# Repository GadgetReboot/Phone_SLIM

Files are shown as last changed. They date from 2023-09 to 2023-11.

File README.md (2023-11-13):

# Phone_SLIM
POTS Telephone Subscriber Line Interface Module
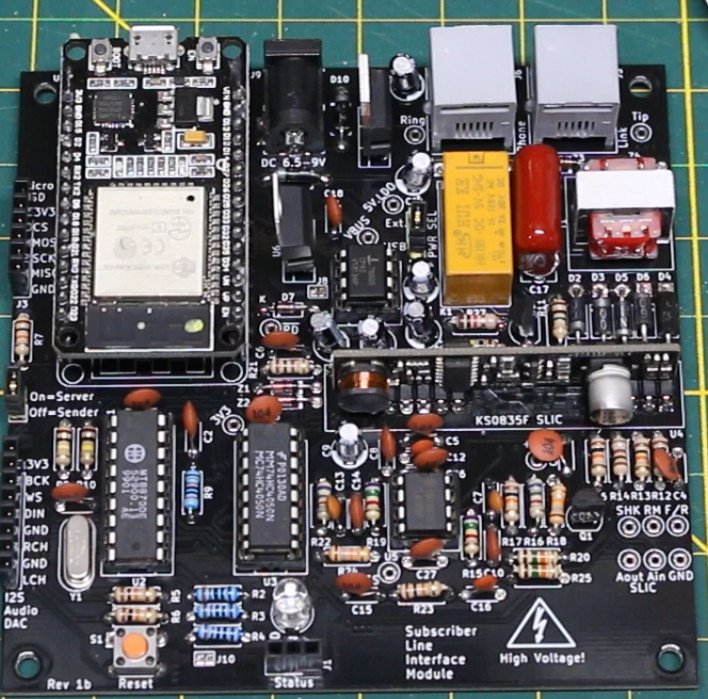
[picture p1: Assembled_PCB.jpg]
PCB
<br><br><BR><BR>
# Usage Notes
> [!NOTE]
> * This project is intended for hobby/personal use to explore how the plain old telephone service works.<br>
> * The PCB isn't designed to integrate with a live phone line. It is intended to create an offline system for local use.<br><br>

* It is recommended to add a TO-220 heat sink to the 3.3v regulator in case it gets too hot. I used [Wakefield-Vette 274-3AB](https://www.digikey.com/en/products/detail/wakefield-vette/274-3AB/2351871)  along with thermal paste and a nut/screw I had around.  <br>
* One pcb is needed for each phone/modem/etc.  One board has to have a jumper installed on J5 to act as a Server node and the other board(s) must have the jumper vacant to act as Sender nodes.<br>
* The Server board must connect to a WiFi router to function properly.  The SSID and Password for the router must be defined by editing the "arduino_secrets.h" file before compiling the sketch.<br>
* The telephone numbers are 7 digits long and are configured by editing the "project_globals.cpp" file and changing the numbers assigned to remotePhoneNumber and localPhoneNumber.<br>
* The region can be configured by uncommenting the desired line in the "project_globals.cpp" file, setting myRegion equal to North America or UK.<br><BR>

* Each board should be powered from an external 5 volt DC supply capable of 500mA since each board can draw several hundred mA.<BR>
* USB power can be used for programming and some testing, but the board may not be as stable as when powered externally.<BR>
* Set the power jumper J8 for USB or EXT as needed.<BR><BR>

# Parts
* The transformer is a 600:600 ohm audio isolation type.  The part used in the prototypes is from Ali Express, such as the red 4 pin ones here with description words such as EL14 included: https://s.click.aliexpress.com/e/_Dmlkp3z <BR><BR>

# Powering Up Two Nodes
* Power up the Server board first and wait for the blue LED to light up on the ESP module's built in LED to indicate it has joined the WiFi router.<br>
* Then power up the Sender board so it can try to auto-pair with the Server board over ESP-NOW.  In the future, software may be improved so the Sender board will auto-pair whenever the Server board is ready.<BR><BR>

* Check out this similar project being worked on: https://github.com/ktownsend-personal/RetroPhone
<br><br>
Shield: [][cc-by-sa]

This work is licensed under a
[Creative Commons Attribution-ShareAlike 4.0 International License][cc-by-sa].

[][cc-by-sa]

[cc-by-sa]: http://creativecommons.org/licenses/by-sa/4.0/
[cc-by-sa-image]: https://licensebuttons.net/l/by-sa/4.0/88x31.png
[cc-by-sa-shield]: https://img.shields.io/badge/License-CC%20BY--SA%204.0-lightgrey.svg

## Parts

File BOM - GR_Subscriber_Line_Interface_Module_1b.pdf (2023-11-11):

Subscriber Line Interface Module BOM

Item # | Reference Designator | Qty | Manufacturer | Mfg Part # | Description / Value | Package/Footprint | Type | Instructions / Notes
1 | C12 C16 | 2 | KYOCERA AVX | SR215C102KARTR1 | CAP CER 1000PF 50V X7R RADIAL | 5mm Pitch | THRU-HOLE
2 | C7 C13 | 2 | TDK | FA28X7R1H682KNU06 | CAP CER 6800PF 50V X7R RADIAL | 5mm Pitch | THRU-HOLE
3 | C1 C2 C3 C4 C5 C6 C8 C10 C11 C14 C15 C18 C24 C25 C26 | 15 | Vishay | K104K15X7RF5TH5 | 0.1 µF ±10% 50V Ceramic Capacitor X7R Radial | 5mm Pitch | THRU-HOLE
4 | C9 C19 C20 C21 C22 C23 | 6 | Panasonic | ECA-1CM100I | 10 µF 16 V Aluminum Electrolytic Capacitor Radial | 2.5mm Pitch | THRU-HOLE
5 | C17 | 1 | Panasonic | ECW-F2105HA | Film Capacitor 1.0uF 250VDC 3% MPP L/S=15mm | Radial | THRU-HOLE
6 | D2 D3 D5 D6 D8 | 5 | Diotec Semiconductor | 1N4004 | Diode 400 V 1A Through Hole DO-41/DO-204AC | DO-41 | THRU-HOLE
7 | D7 | 1 | onsemi | 1N4148 | Diode 100 V 200mA Through Hole DO-35 | DO-35 | THRU-HOLE
8 | D9 | 1 | Diodes Inc | 1N5817-T | DIODE SCHOTTKY 20V 1A DO41 | DO-41 | THRU-HOLE
9 | D1 | 1 | Everlight Electronics Co Ltd | EALP05RDMRGBA0 | 5mm RGB LED Common Anode | 5mm, T-1 3/4 | THRU-HOLE
10 | D4 | 1 | Littelfuse Inc. | P6KE82CA | TVS DO15 70.1V 600W BIDIR | DO-15 | THRU-HOLE
11 | J5 | 1 | Sullins | PREC002SAAN-RC | Connector Header Through Hole 2 position 0.100" | 2POS | THRU-HOLE
12 | J1 | 0 | | | | | | Do Not Install
13 | J4 | 0 | | | | | | Do Not Install
14 | J2 | 0 | | | | | | Do Not Install
15 | J3 J9 | 0 | | | | | | Do Not Install
16 | J8 | 1 | Sullins | PREC003SAAN-RC | Connector Header Through Hole 3 position 0.100" | 3POS | THRU-HOLE
17 | J10 | 1 | CUI Devices | PJ-202A | Power Barrel Jack 2.10mm ID, 5.50mm OD Through Hole, Right Angle 3POS | | THRU-HOLE
18 | J6 J7 | 2 | Ckmtw(Shenzhen Cankemeng) | R-RJ11R06P-A800 | RJ11 RJ Receptacle Modular Connector | 6POS | THRU-HOLE
19 | J11 | 1 | Phoenix Contact | 5442206 | TERM BLK 2P SIDE ENT 5.08MM PCB | 2POS | THRU-HOLE
20 | K1 | 1 | Ningbo Keke New Era Appliance | HK19F-DC5V-SHG（Y) | Relay DPDT 5VDC Coil | 8PIN | THRU-HOLE
21 | Q2 | 1 | Onsemi | 2N3904TA | BJT NPN Transistor General Purpose | TO-92 135AR Leadformed | THRU-HOLE
22 | Q1 | 1 | Onsemi | 2N7000 | MOSFET TO92 N 60V 0.2A 5OHM 150C | TO-92 | THRU-HOLE
23 | R14 R21 | 2 | YAGEO | CFR-25JR-52-100R | RES 100 OHM 5% 1/4W AXIAL | Axial | THRU-HOLE
24 | R1 R3 R4 | 3 | YAGEO | CFR-25JR-52-300R | RES 300 OHM 5% 1/4W AXIAL | Axial | THRU-HOLE
25 | R27 | 1 | YAGEO | CFR-25JR-52-1K | RES 1K OHM 5% 1/4W AXIAL | Axial | THRU-HOLE
26 | R16 R22 | 2 | YAGEO | CFR-25JR-52-6K8 | RES 6.8K OHM 5% 1/4W AXIAL | Axial | THRU-HOLE
27 | R15 R19 R25 | 3 | YAGEO | CFR-25JR-52-7K5 | RES 7.5K OHM 5% 1/4W AXIAL | Axial | THRU-HOLE
28 | R2 R5 R6 R7 R12 R13 R17 R23 R26 | 9 | YAGEO | CFR-25JR-52-10K | RES 10K OHM 5% 1/4W AXIAL | Axial | THRU-HOLE
29 | R20 | 1 | YAGEO | CFR-25JR-52-15K | RES 15K OHM 5% 1/4W AXIAL | Axial | THRU-HOLE
30 | R18 R24 | 2 | YAGEO | CFR-25JR-52-18K | RES 18K OHM 5% 1/4W AXIAL | Axial | THRU-HOLE
31 | R8 R10 R28 | 3 | YAGEO | CFR-25JR-52-100K | RES 100K OHM 5% 1/4W AXIAL | Axial | THRU-HOLE
32 | R9 | 1 | YAGEO | CFR-25JR-52-300K | RES 300K OHM 5% 1/4W AXIAL | Axial | THRU-HOLE
33 | R11 | 1 | YAGEO | CFR-25JR-52-1M | RES 1Meg OHM 5% 1/4W AXIAL | Axial | THRU-HOLE
34 | S1 | 1 | TE Connectivity | 1825910-6 | 50mA Straight SPST 160gf 24V Plugin Tactile Switch | 4PIN | THRU-HOLE
35 | T1 | 1 | Sunrom | 5132 | Audio Isolation Transformer 600:600 Ohm 1:1 EI14 | 4 lead | THRU-HOLE | Info: https://www.sunrom.com/m/5132
36 | U3 | 1 | Texas Instruments | CD74HC4050E | IC BUFFER NON-INVERT 6V 16DIP | DIP16 | THRU-HOLE
37 | U1 | 2 | Sullins | PPTC151LFBN-RC | CONN HDR 15POS 0.1 TIN PCB | 15POS | THRU-HOLE | Two 15 pin female headers are installed so the user can plug in ESP32_DevKit_V1_DOIT module. For best alignment plug an ESP32 module into the headers and then solder to PCB.
38 | U7 | 1 | Renesas | ICL7660SIPAZ | IC REG CHARGE PUMP INV 45MA 8DIP | DIP8 | THRU-HOLE
39 | U4 | 1 | Shenzhen Ring&Tone | KS0835F | RING Subscriber Line Interface Circuit Module | SIP Special | THRU-HOLE | Purchased from AliExpress. Manufacturer: http://www.r-tone.com/contact-us
40 | U6 | 1 | ST Micro | LD1117AV33 | IC REG LINEAR 3.3V 1A TO220AB | TO-220 | THRU-HOLE

41 | U5 | 1 | Texas Instruments | LM358P | IC OPAMP GP 2 CIRCUIT 8DIP | DIP-8 | THRU-HOLE
42 | U2 | 1 | Microchip | MT8870DE1 | IC TELECOM INTERFACE 18DIP | DIP18 | THRU-HOLE
43 | Y1 | 1 | Abracon | ABL-3.579545MHZ-B2 | 3.579545 MHz ±20ppm Crystal 18pF 180 Ohms HC-49/US | HC-49/US | THRU-HOLE
44 | Z1 Z2 Z3 Z4 | 4 | Vishay | BZX55B2V4-TAP | DIODE ZENER 2.4V 500MW DO35 | DO-35 | THRU-HOLE

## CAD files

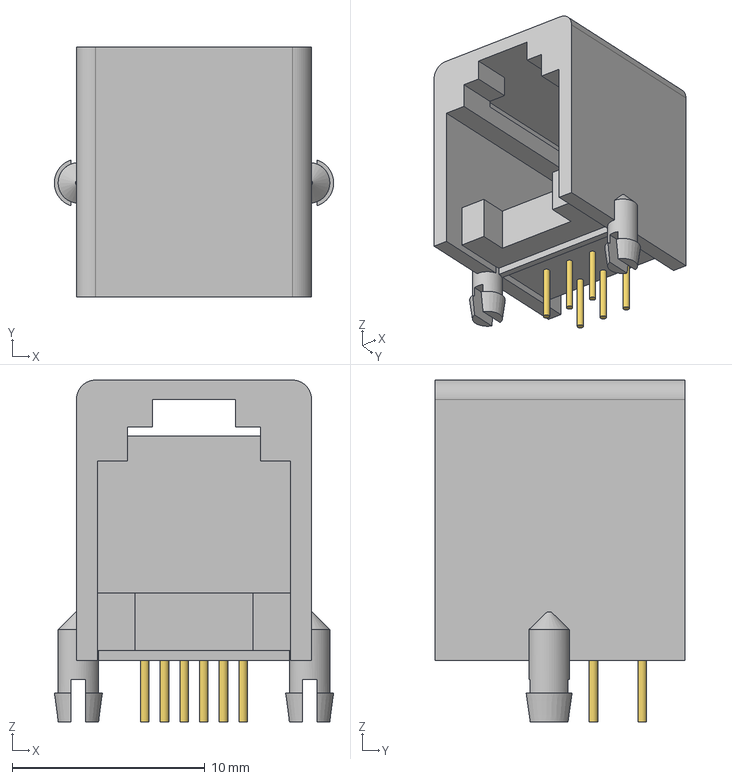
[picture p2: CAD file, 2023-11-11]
KiCad/3D_Models/TJ6P6C.stp
14.5 x 13.0 x 17.8 mm

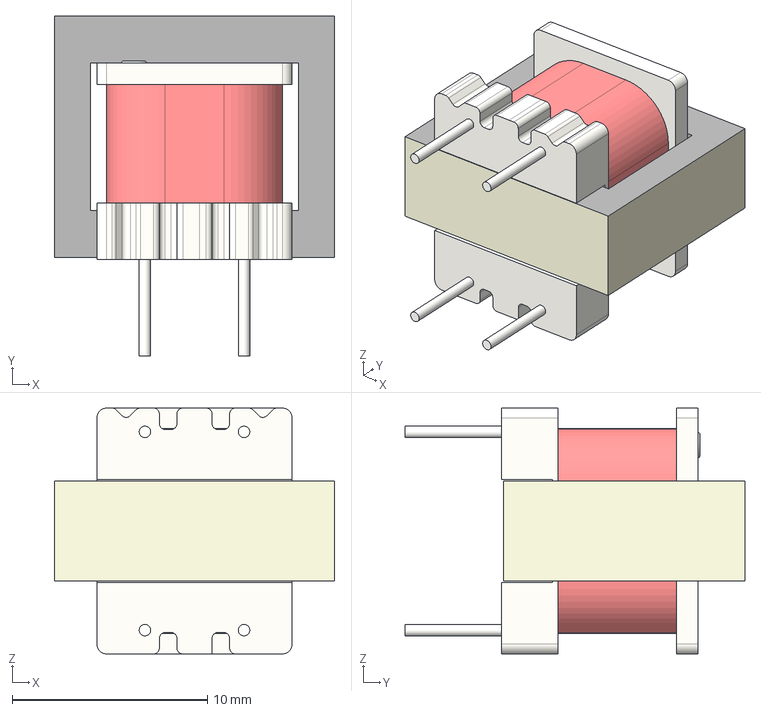
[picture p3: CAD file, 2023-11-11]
KiCad/3D_Models/EE14 Red Audio Transformer v3.step
14.3 x 17.4 x 12.6 mm

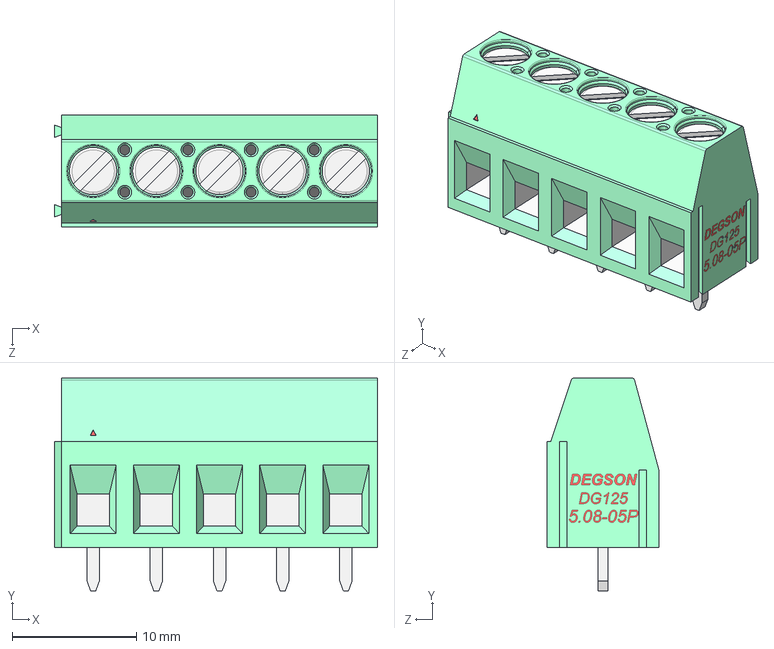
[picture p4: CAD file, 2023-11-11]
KiCad/3D_Models/DG125-5.08-05P-14-00AH.STEP
26.0 x 17.1 x 9.00 mm

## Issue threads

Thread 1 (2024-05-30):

Various errors loading Sketch

DAN-GITHUB-ACCESS, 2024-05-30:
Hello Gadget Reboot, I am contacting you here because I did not find any other information.

I ordered 5 Phone Line Simulator (POTS Land Line) boards from PCBWAY.

I would like to customize it so that I have a button. When I press the button the phone starts ringing. When the phone is answered, a greeting and then music is played from an SD card. If it is not answered, the ringing will stop after 5 times.

I haven't done that much with Arduino and not with such complex sketches.

But my problem is that when I want to load your sketch. Many errors are displayed that modules are missing.

Would it be possible to get a sketch where all modules are included and the required #INCLUDE is not <excluded>.

Thx Danny

GadgetReboot, 2024-05-30:
I don't know a lot about software so I was lucky to get everything working and I know things can break if new libraries are released or different board files for the chip being used.
What errors did you get?
I will try to flash the sketch in a newer Arduino IDE setup and see if it works easily or what I needed to do to get libraries installed.

GadgetReboot, 2024-05-31:
I just installed the latest Arduino IDE fresh on a clean system that has never had any of the files on it so there would be no residual things that get overlooked.
The first thing I'd try is verify which version of the ESP32 board file you are using because somewhere after the version 1 series, things started giving compile errors.
I used ESP32 board file version 1.0.6   and a bunch of weird errors went away.   If you use a newer board file you can temporarily downgrade to 1.0.6 and then upgrade again after, or set up a different IDE for using weird occasional configurations.   I don't know why the errors are there or if they're due to other libraries not working well together so I just lived with the dependency.

Here's the long list of exactly what I did from scratch:

SLIM_node Sketch Upload from scratch
Install Arduino IDE 2.3.2
Download sketch and unzip in folder called SLIM_node, and open the sketch in the IDE
Configure Arduino IDE for  ESP32 board file support following instructions on Espressif page, using Stable release link in Arduino preferences board manager URL  https://docs.espressif.com/projects/arduino-esp32/en/latest/installing.html
Then in Arduino IDE menu Tools/Board/Boards Manager,  search for ESP and install ESP by espressif  1.0.6   Newer board files cause compile errors
Choose the correct ESP32 board in Tools/Board/ESP32/DOIT ESP32 DEVKIT V1
Without having installed any other libraries yet, going step by step, clicking Verify to compile and check for errors, it can’t find RGBLed.h  so installed that by going to https://github.com/wilmouths/RGBLed   and clicking the green Code button, choose download zip and save it.
In the IDE choose menu item Sketch, Include Library, Add .Zip Library.  Navigate to the downloaded Zip file and click Open to install it.
Compiling again, it can’t find ESPAsyncWebServer
Install by going to https://github.com/me-no-dev/ESPAsyncWebServer and following the same procedure to download the zip and install the library.
Compiling again, it can’t find AsyncTCP
Install the same way from https://github.com/me-no-dev/AsyncTCP
Compiling again, it can’t find ArduinoJSON
Go to IDE menu Sketch/Include Library/Manage Libraries and search for ArduinoJSON by Benoit Blanchon.  Install version 6.19.4  since this was the version used for testing originally.
Compiling again, it can’t find MozziGuts.
Install Mozzi by going to https://github.com/sensorium/Mozzi and installing the library zip file with previous methods
Compile successful!

DAN-GITHUB-ACCESS, 2024-05-31:
Hello
Thank you for this fast answer.

Setup

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

Use Sketch from repository

Verify Sketch

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

RGBLed.h highlighted in the sketch.
RGBLed.h not included in the sketch folder

comment out

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

Verify Sketch

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

ESPAsyncWebServer.h highlighted in the sketch.
WiFi.h and ESPAsyncWebServer.h not included in the sketch folder

GadgetReboot, 2024-05-31:
Yeah those libraries need to be installed by downloading the zip files the way I described in my clean setup yesterday and then it should compile.

DAN-GITHUB-ACCESS, 2024-05-31:
Oh sorry, I didn't see the email at first. What is needed from the Mozzi .zip? everything ?

DAN-GITHUB-ACCESS, 2024-05-31:
Thank you very much, it worked.

Last question. When I use the board with an external power supply. Can I still use the USB port on the board for programming at the same time, or do I just have to use USB?

GadgetReboot, 2024-06-01:
Since the IDE is installing the whole zip library I just kept it all because it would probably break if I tried to delete files and it happens to need them.
External power and usb can be plugged in at the same time because diodes on the ESP module as well as the board prevent any back feeding if multiple sources are in use.

DAN-GITHUB-ACCESS, 2024-06-01:
Thank you again for your help and creating this board.

DAN-GITHUB-ACCESS, 2024-06-27:
Can you give me some help again?

How can I start and stop the ringing on the same board.
I only made it to the other board using a "sendTrunkMsg" message.

Thank you very much.

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

GadgetReboot, 2024-06-27:
It's been a while since I was doing testing with just making a phone ring on one board and I can't find any test code so if I were looking to add some kind of extra feature to the main code, I'd check if there's a spare input pin available on the ESP32 I can use to trigger a ring (can't remember if there's extra pins now).

Then I'd add some extra conditions to the runStateMachine()   part of the main INO sketch file to force a ring generating state as if someone were trying to call in from the other board.

There is a state called ringPhone   that gets assigned to  currState   when an incoming call normally rings the phone so I'd want to trigger that state in a test mode.

So in the case  Idle:      part of the runStateMachine() function, there's some if-statements there that wait for an event to go do something besides sit waiting for a command.
The last if-statement there  looks like:
      if (remoteRequestType == INCOMING_CALL) {
        clearRemoteNodeData();                           
        enteringNewState = true;
        currState = ringPhone;                           
      }

So I'd add a new if-statement right after that one that maybe does something like
if (reading in that spare GPIO test-ring pin is low) {
        enteringNewState = true;
        currState = ringPhone;                           
      }

Then there would be that extra way to make the local phone ring other than an income call message to ring it, by setting a spare pin low or whatever other method can be used to trigger it, and the state machine jumps to the phone ring part.

Then to make the phone stop ringing of course, just pick it up and hang it up, or else hack in more if-statements to look for something like another GPIO low level reading to make it stop.

It looks like the only unused gpio pins are 1 2 and 3 on the schematic, 1 and 3 are UART and pin 2 is the on board LED for the module, so just for an experiment maybe one of those three can be assigned as input with pull up at the end of the setup() function and read in during that new if-statement to check if it's low and do the test ring.  I'd probably try gpio 2 (LED) since it is less likely to be used as an LED after the first setup lines of code (it's used to show when wifi is joined, which happens earlier in setup).

DAN-GITHUB-ACCESS, 2024-06-28:
Thanks for the help.

My board automatically starts in server mode and I can use the pin for a button.

I have now found that when I set the trigger with the button, the circuit first needs a status change. idle -> off-hook -> idle. then the phone rings.
So I would have to reinitialize the runStateMachine after pressing the button. But somehow that doesn't work.

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

DAN-GITHUB-ACCESS, 2024-06-28:
I did it. I was able to work with "enteringNewState“.

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

GadgetReboot, 2024-06-28:
Good that it worked - I'd have to get all back into the mindset to even remember how it all works after half a year away from it, and I don't have anything set up to even test with right now.  I had to use the ESP modules in another project.  But I'll be getting back at it maybe in a few months with a new audio switching board I now have so it can route calls between multiple nodes.  It'll take a bunch of hacking and slashing of software before that gets working and I'll have to re-learn how the messages function so I can intercept them and use them for multi node routing.

DAN-GITHUB-ACCESS, 2024-06-28:
Sounds interesting. Keep us informed about these cool things.

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

VladIPlay, 2025-01-14:
Hi, i found your board and videos on youtube and got sucked up into this rabbit hole :)
I will order some PCBs to play with it but i would want to know if it is possible to record on the SD card the 'calls'.
My idea is to show my nephews how phones were in the past and make them some games using landline phones.
As a bonus, i will try to add a mmwave sensor to trigger the phone to ring or something like this to make it more fun.
I am new to tinkering with electronics but with the software part i think i will manage.

VladIPlay, 2025-01-14:
Hi, i found your board and videos on youtube and got sucked up into this rabbit hole :)
I will order some PCBs to play with it but i would want to know if it is possible to record on the SD card the 'calls'.
My idea is to show my nephews how phones were in the past and make them some games using landline phones.
As a bonus, i will try to add a mmwave sensor to trigger the phone to ring or something like this to make it more fun.
I am new with tinkering with electronics but with the software part i think i will manage.

GadgetReboot, 2025-01-14:
> Hi, i found your board and videos on youtube and got sucked up into this rabbit hole :) I will order some PCBs to play with it but i would want to know if it is possible to record on the SD card the 'calls'.

I haven't tried so you'd have to experiment by using a reference project for SD read/write and put the code in the phone sketch and make sure it doesn't clash with anything else in the sketch.
Another way to save data just in the ESP32 flash directly is saving data using Preferences.   I also haven't done that before and it would have to be tested to make sure nothing clashes but I'd start with an example like this
https://randomnerdtutorials.com/esp32-save-data-permanently-preferences/

GadgetReboot, 2025-01-14:
.

GadgetReboot, 2025-01-14:
.

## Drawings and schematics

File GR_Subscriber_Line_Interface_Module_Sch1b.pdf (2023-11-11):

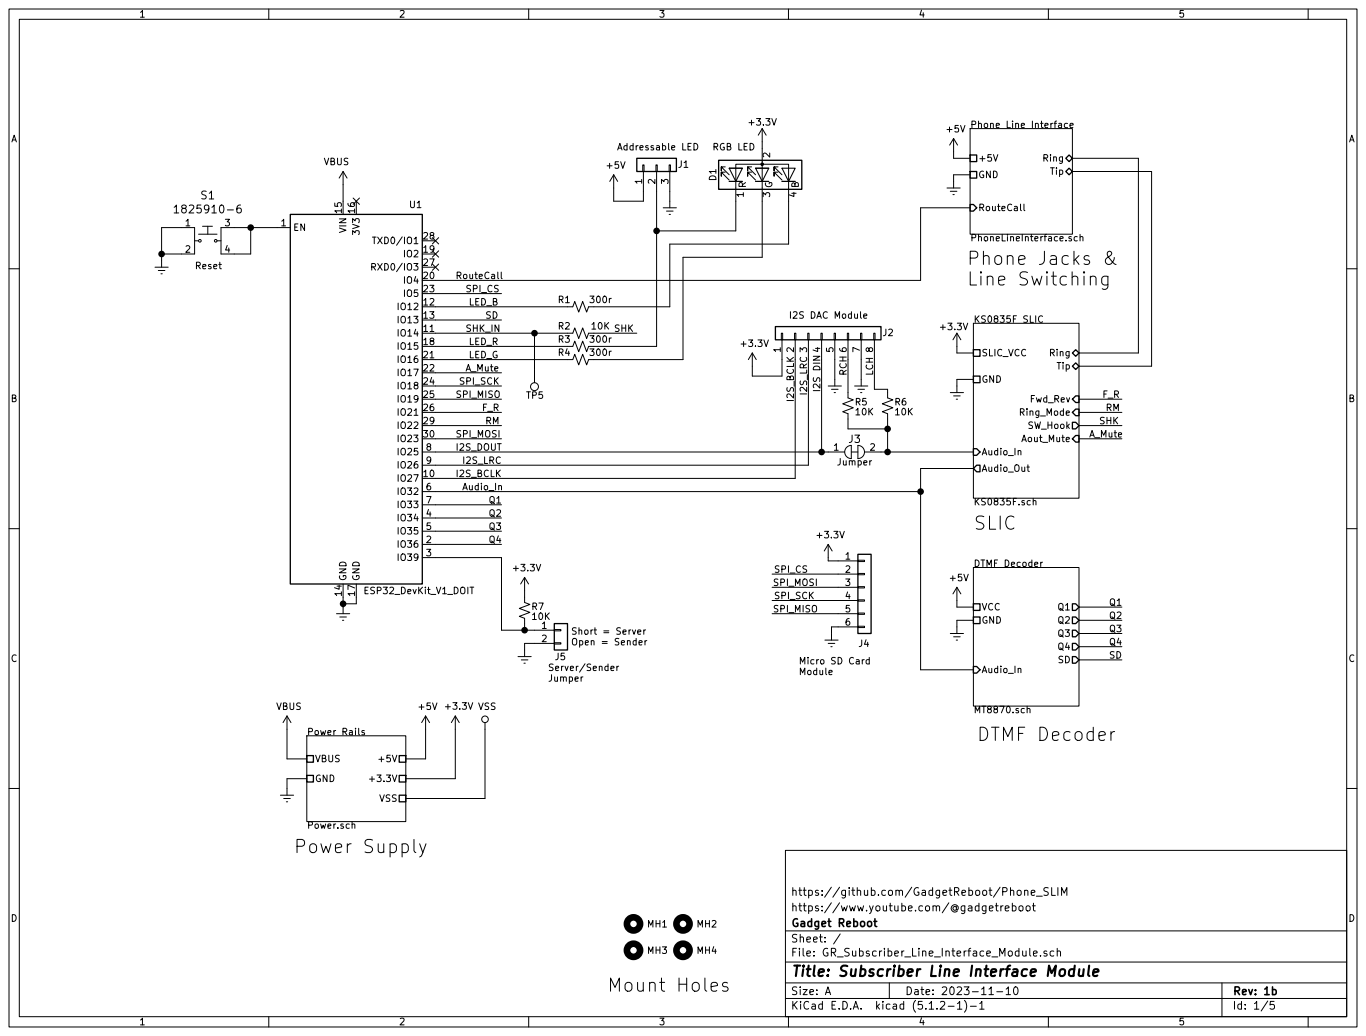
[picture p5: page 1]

I2S_LRC | I2S DIN | Jumper I2S_BCLK RCH LCH

A_Mute Power Rails Power.sch VBUS GND

I2S_LRC

https://github.com/GadgetReboot/Phone_SLIM
https://www.youtube.com/@gadgetreboot
File: GR_Subscriber_Line_Interface_Module.sch Sheet: / Gadget Reboot

Id: 1/5 Title: Subscriber Line Interface Module

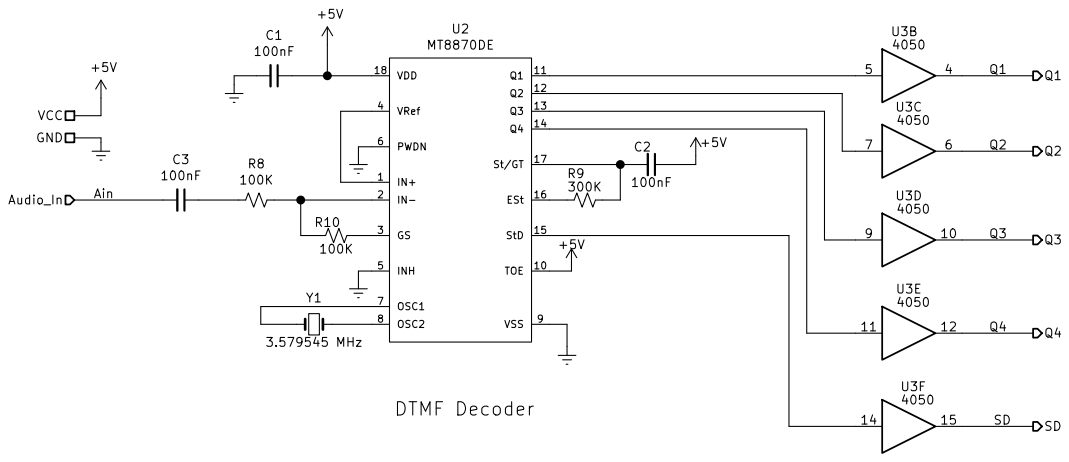
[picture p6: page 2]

https://github.com/GadgetReboot/Phone_SLIM
https://www.youtube.com/@gadgetreboot
File: MT8870.sch Sheet: /DTMF Decoder/ Gadget Reboot

Id: 2/5 Title: Subscriber Line Interface Module

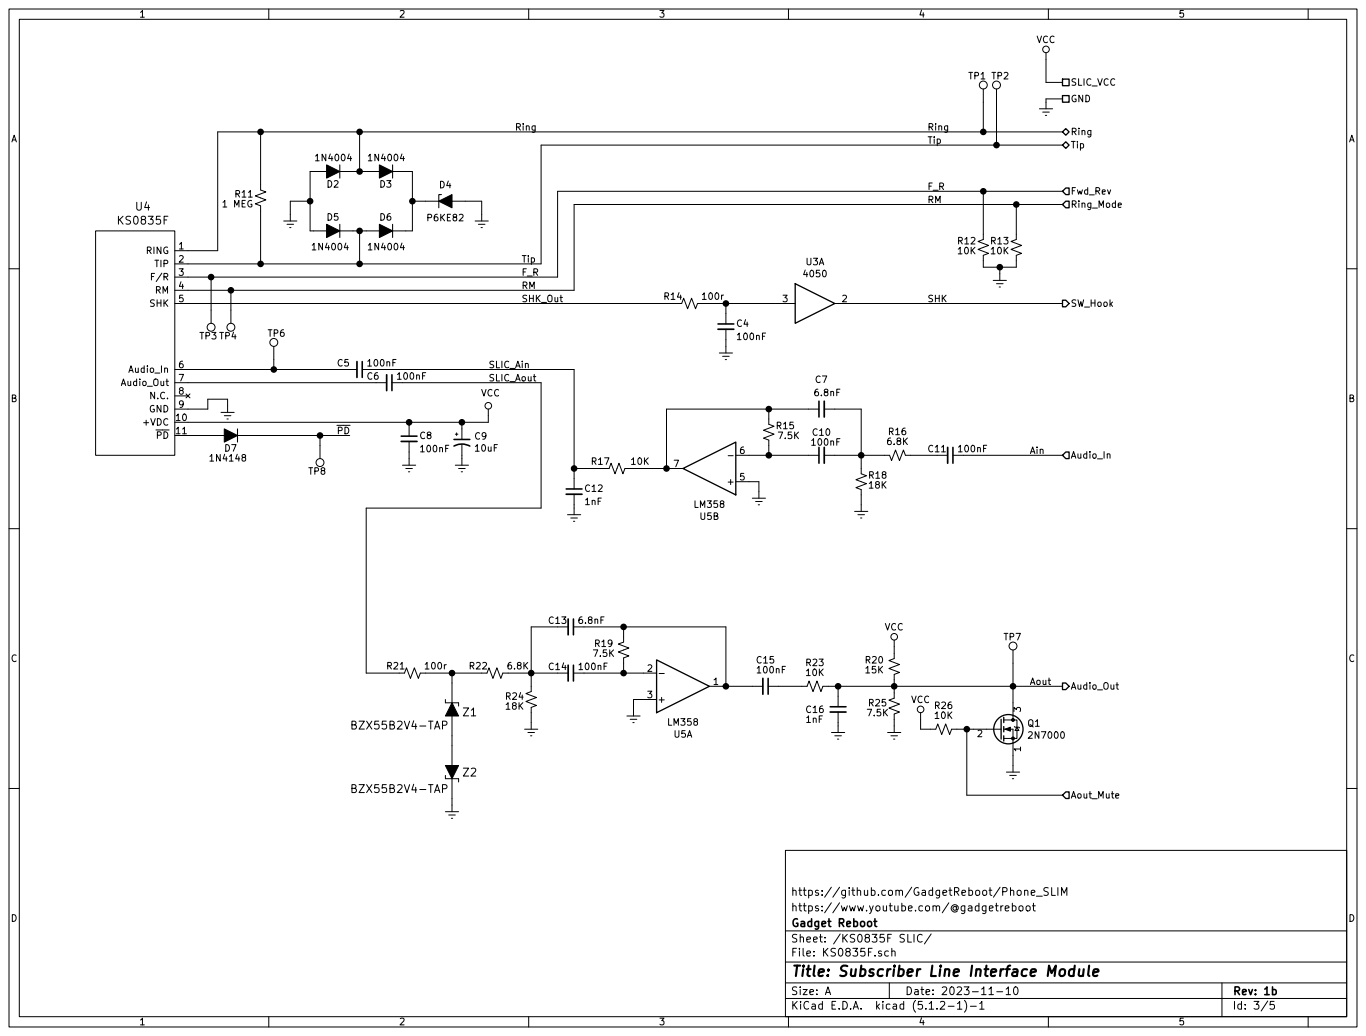
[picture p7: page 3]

https://github.com/GadgetReboot/Phone_SLIM
https://www.youtube.com/@gadgetreboot
File: KS0835F.sch Sheet: /KS0835F SLIC/ Gadget Reboot

Id: 3/5 Title: Subscriber Line Interface Module

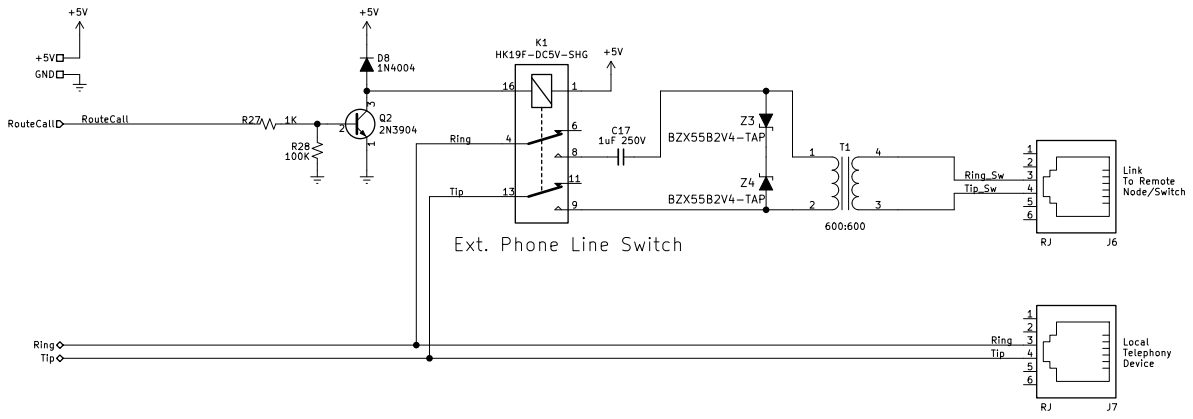
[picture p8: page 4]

Local Telephony Device Ring +5V GND

Link To Remote Node/Switch R28

https://github.com/GadgetReboot/Phone_SLIM
https://www.youtube.com/@gadgetreboot
File: PhoneLineInterface.sch Sheet: /Phone Line Interface/ Gadget Reboot

Id: 4/5 Title: Subscriber Line Interface Module

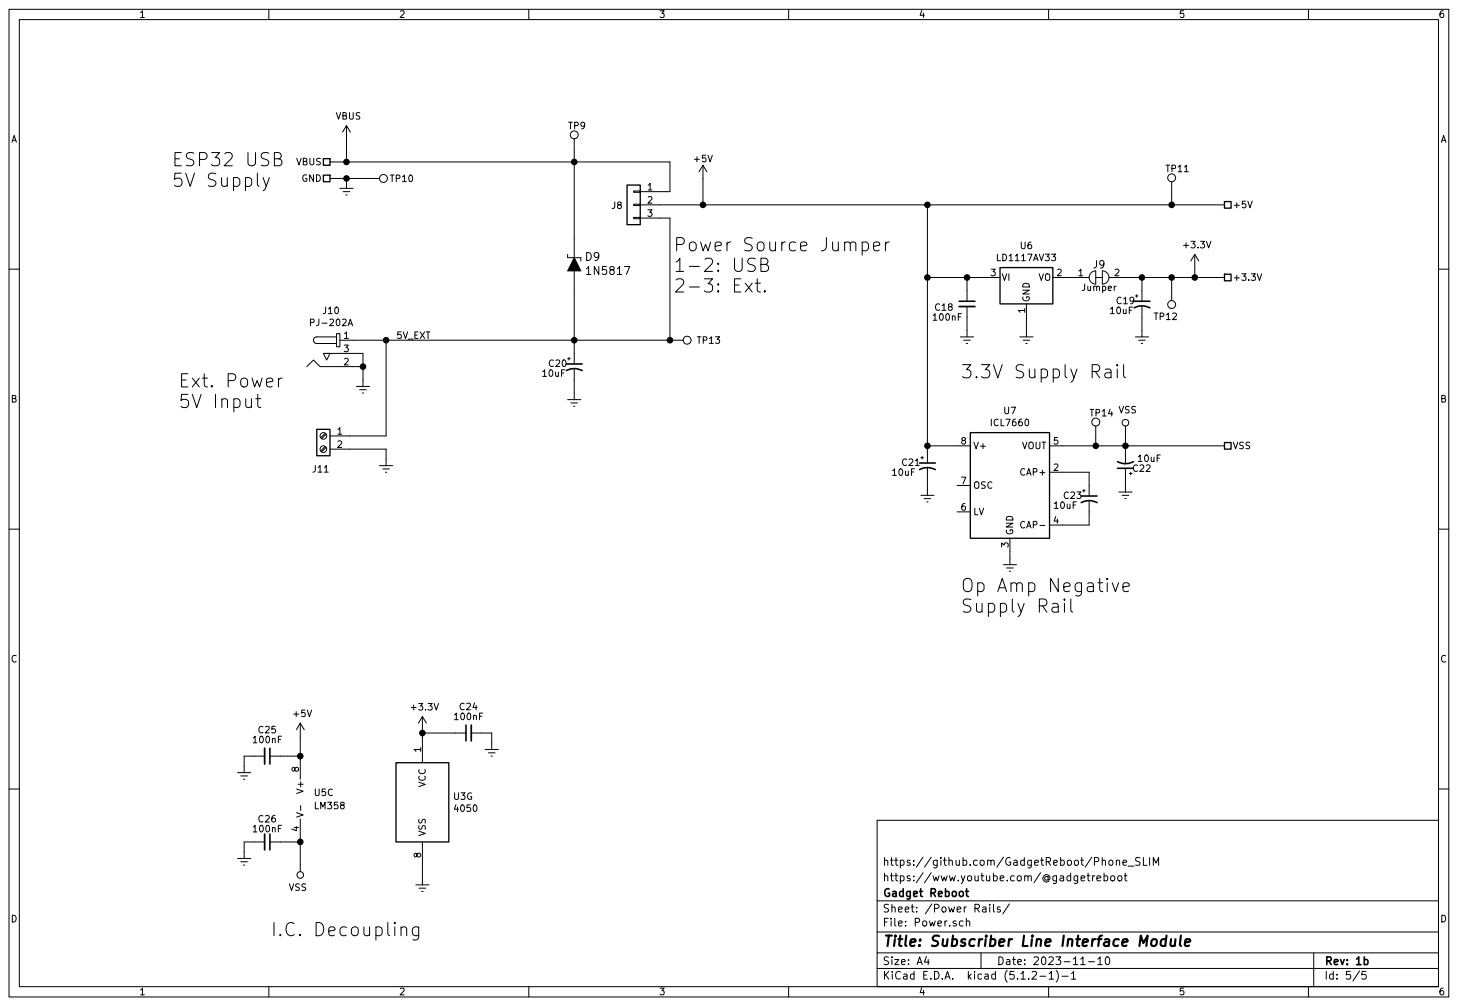
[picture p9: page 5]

https://github.com/GadgetReboot/Phone_SLIM V- 4 V+

https://www.youtube.com/@gadgetreboot
File: Power.sch Sheet: /Power Rails/ Gadget Reboot

Id: 5/5 Title: Subscriber Line Interface Module

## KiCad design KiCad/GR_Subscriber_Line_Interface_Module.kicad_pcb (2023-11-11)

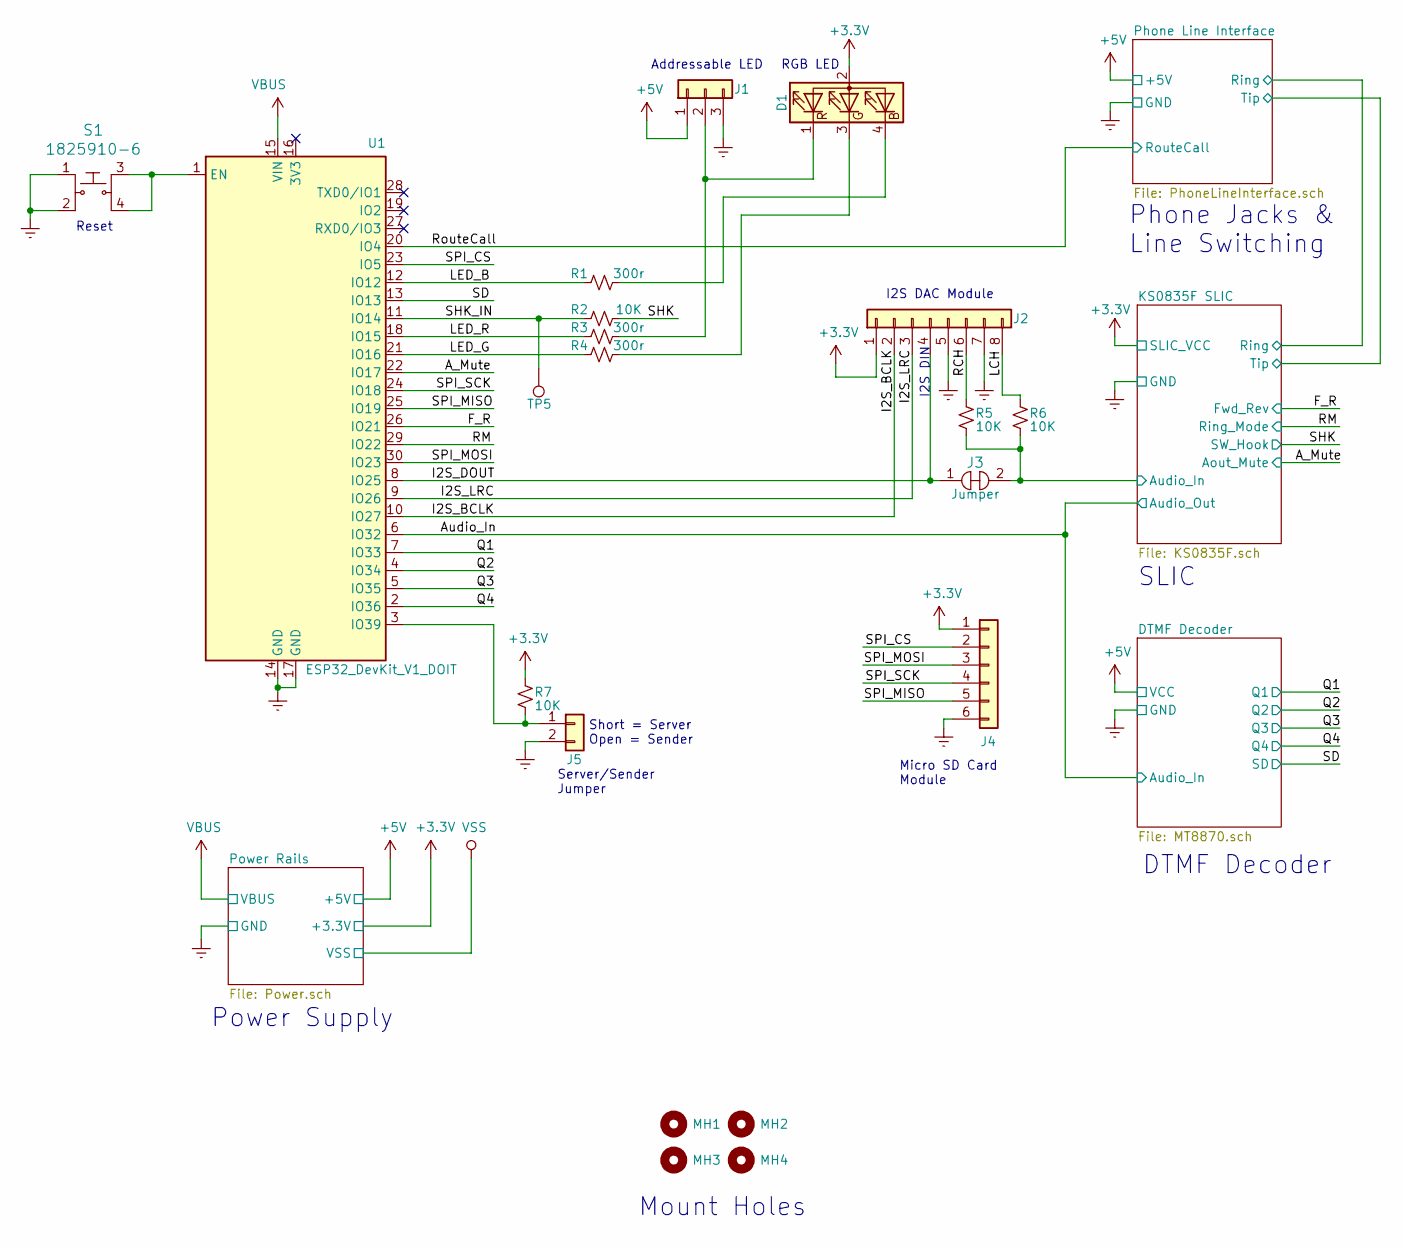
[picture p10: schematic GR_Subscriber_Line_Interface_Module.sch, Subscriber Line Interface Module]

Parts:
D1: LED_RAGB; LED_D5.0mm-4_RGB
J1: Conn_01x03; PinHeader_1x03_P2.54mm_Vertical
J2: Conn_01x08; PinHeader_1x08_P2.54mm_Vertical
J3: Jumper; SolderJumper-2_P1.3mm_Bridged_Pad1.0x1.5mm
J4: Conn_01x06; PinHeader_1x06_P2.54mm_Vertical
J5: Conn_01x02; PinHeader_1x02_P2.54mm_Vertical
MH1, MH2, MH3, MH4: MountingHole; MountingHole_3.2mm_M3
R1, R3, R4: 300r; R_Axial_DIN0207_L6.3mm_D2.5mm_P10.16mm_Horizontal
R2, R5, R6, R7: 10K; R_Axial_DIN0207_L6.3mm_D2.5mm_P10.16mm_Horizontal
S1: 1825910-6; Switch_Tactile_THT_6x6mm; MPN 1825910-6; Digi-Key_PN 450-1650-ND
TP5: TestPoint; TestPoint_Loop_D2.60mm_Drill1.4mm_Beaded
U1: ESP32_DevKit_V1_DOIT; esp32_devkit_v1_doit

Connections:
+3V3: D1.2 (A), J2.1, J4.1, R7.2; also elsewhere on the board
+5V: J1.1; also elsewhere on the board
/A_Mute: U1.22 (IO17); also elsewhere on the board
/Audio_In: U1.6 (IO32); also elsewhere on the board
/F_R: U1.26 (IO21); also elsewhere on the board
/I2S_BCLK: J2.2, U1.10 (IO27)
/I2S_DOUT: J2.4, J3.1, U1.8 (IO25)
/I2S_LRC: J2.3, U1.9 (IO26)
/KS0835F SLIC/Audio_In: J3.2, R5.1, R6.1; also elsewhere on the board
/LCH: J2.8, R6.2
/LED_B: R1.1, U1.12 (IO12)
/LED_G: R4.1, U1.21 (IO16)
/LED_R: R3.1, U1.18 (IO15)
/Q1: U1.7 (IO33); also elsewhere on the board
/Q2: U1.4 (IO34); also elsewhere on the board
/Q3: U1.5 (IO35); also elsewhere on the board
/Q4: U1.2 (IO36); also elsewhere on the board
/RCH: J2.6, R5.2
/RM: U1.29 (IO22); also elsewhere on the board
/RouteCall: U1.20 (IO4); also elsewhere on the board
/SD: U1.13 (IO13); also elsewhere on the board
/SHK: R2.2; also elsewhere on the board
/SHK_IN: R2.1, TP5.1, U1.11 (IO14)
/SPI_CS: J4.2, U1.23 (IO5)
/SPI_MISO: J4.5, U1.25 (IO19)
/SPI_MOSI: J4.3, U1.30 (IO23)
/SPI_SCK: J4.4, U1.24 (IO18)
GNDREF: J1.3, J2.5, J2.7, J4.6, J5.2, S1.1, S1.2, U1.14 (GND), U1.17 (GND); also elsewhere on the board
unnamed: D1.1 (RK), J1.2, R3.2
unnamed: D1.3 (GK), R4.2
unnamed: D1.4 (BK), R1.2
unnamed: J5.1, R7.1, U1.3 (IO39)
unnamed: S1.3, S1.4, U1.1 (EN)
VBUS: U1.15 (VIN); also elsewhere on the board

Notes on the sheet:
Mount Holes
DTMF Decoder
SLIC
Phone Jacks & Line Switching
Short = Server Open = Sender
Server/Sender Jumper
Power Supply
I2S DAC Module
Micro SD Card Module
Addressable LED
RGB LED
Reset
I2S DIN

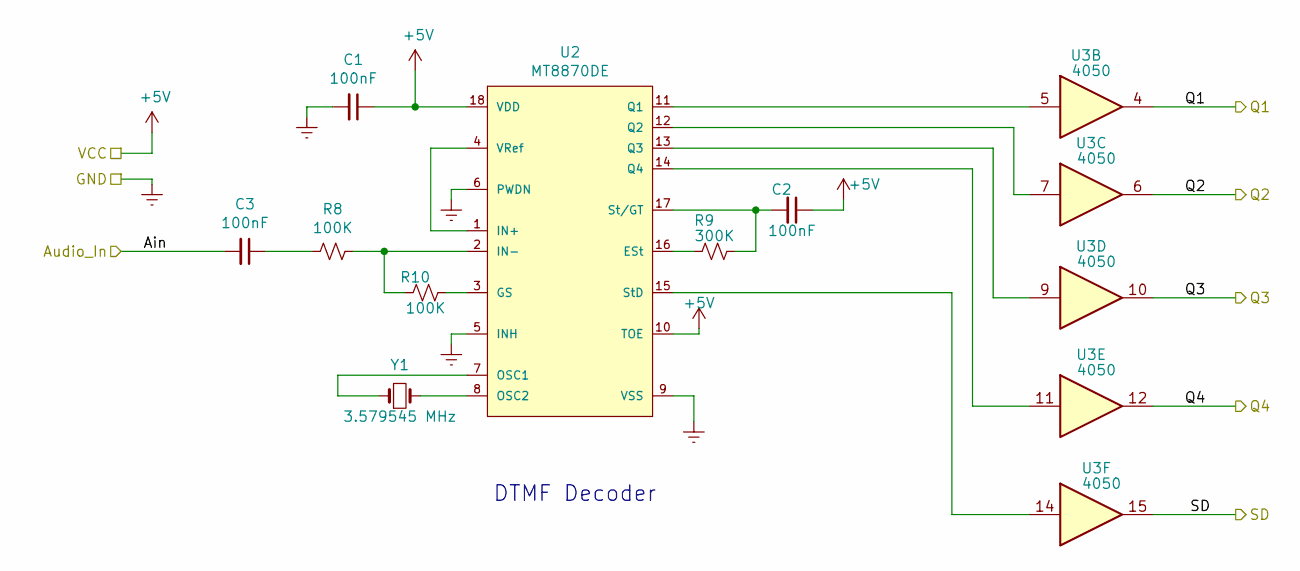
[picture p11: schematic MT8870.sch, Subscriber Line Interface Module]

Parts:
C1, C2, C3: 100nF; C_Disc_D4.3mm_W1.9mm_P5.00mm
R8, R10: 100K; R_Axial_DIN0207_L6.3mm_D2.5mm_P10.16mm_Horizontal
R9: 300K; R_Axial_DIN0207_L6.3mm_D2.5mm_P10.16mm_Horizontal
U2: MT8870DE; DIP-18_W7.62mm_Socket
U3: 4050; DIP-16_W7.62mm_Socket_LongPads
Y1: 3.579545 MHz; Crystal_HC49-4H_Vertical

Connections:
+5V: C1.1, C2.1, U2.10 (TOE), U2.18 (VDD); also elsewhere on the board
/Audio_In: C3.2; also elsewhere on the board
/Q1: U3.4; also elsewhere on the board
/Q2: U3.6; also elsewhere on the board
/Q3: U3.10; also elsewhere on the board
/Q4: U3.12; also elsewhere on the board
/SD: U3.15; also elsewhere on the board
GNDREF: C1.2, U2.5 (INH), U2.6 (PWDN), U2.9 (VSS); also elsewhere on the board
unnamed: C2.2, R9.1, U2.17 (St/GT)
unnamed: C3.1, R8.2
unnamed: R9.2, U2.16 (ESt)
unnamed: R10.1, U2.3 (GS)
unnamed: R8.1, R10.2, U2.2 (IN-)
unnamed: U2.1 (IN+), U2.4 (VRef)
unnamed: U2.7 (OSC1), Y1.1
unnamed: U2.8 (OSC2), Y1.2
unnamed: U2.11 (Q1), U3.5
unnamed: U2.12 (Q2), U3.7
unnamed: U2.13 (Q3), U3.9
unnamed: U2.14 (Q4), U3.11
unnamed: U2.15 (StD), U3.14

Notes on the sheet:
DTMF Decoder

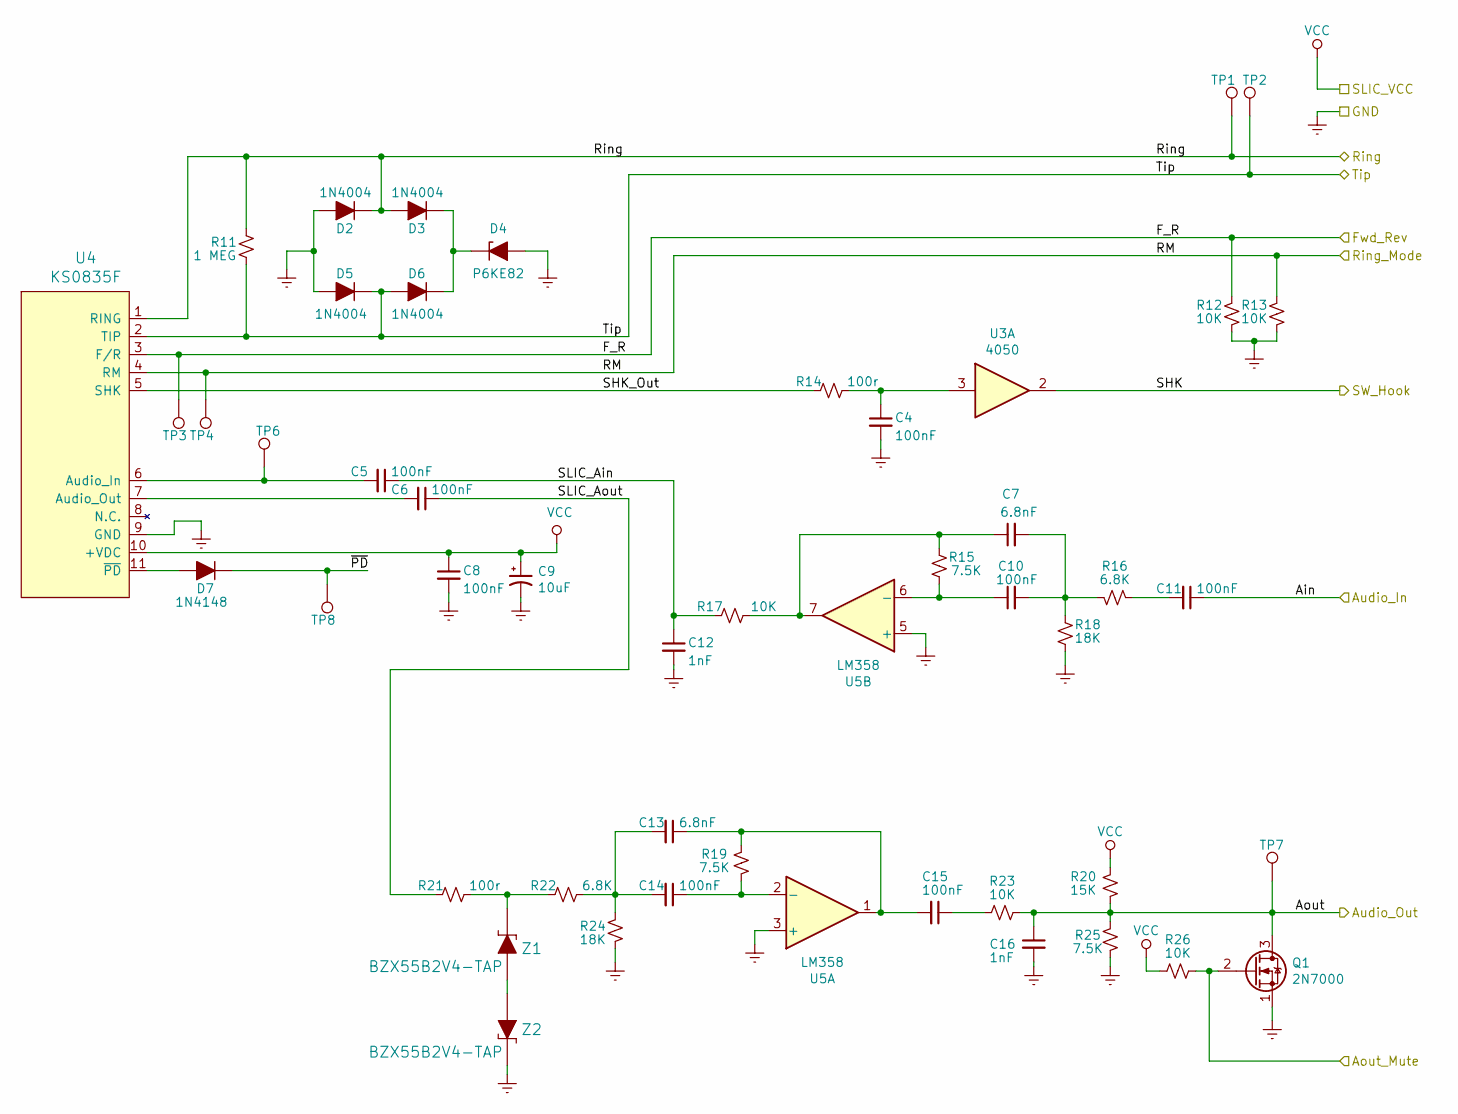
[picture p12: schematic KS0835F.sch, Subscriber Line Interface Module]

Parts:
C4, C5, C6, C8, C10, C11, C14, C15: 100nF; C_Disc_D4.3mm_W1.9mm_P5.00mm
C7, C13: 6.8nF; C_Disc_D4.3mm_W1.9mm_P5.00mm
C9: 10uF; CP_Radial_D5.0mm_P2.50mm
C12, C16: 1nF; C_Disc_D4.3mm_W1.9mm_P5.00mm
D2, D3, D5, D6: 1N4004; D_DO-41_SOD81_P10.16mm_Horizontal
D4: P6KE82; D_DO-41_SOD81_P10.16mm_Horizontal
D7: 1N4148; D_DO-35_SOD27_P7.62mm_Horizontal
Q1: 2N7000; TO-92_Inline
R11: 1 MEG; R_Axial_DIN0207_L6.3mm_D2.5mm_P10.16mm_Horizontal
R12, R13, R17, R23, R26: 10K; R_Axial_DIN0207_L6.3mm_D2.5mm_P10.16mm_Horizontal
R14, R21: 100r; R_Axial_DIN0207_L6.3mm_D2.5mm_P10.16mm_Horizontal
R15, R19, R25: 7.5K; R_Axial_DIN0207_L6.3mm_D2.5mm_P10.16mm_Horizontal
R16, R22: 6.8K; R_Axial_DIN0207_L6.3mm_D2.5mm_P10.16mm_Horizontal
R18, R24: 18K; R_Axial_DIN0207_L6.3mm_D2.5mm_P10.16mm_Horizontal
R20: 15K; R_Axial_DIN0207_L6.3mm_D2.5mm_P10.16mm_Horizontal
TP1, TP2, TP3, TP4, TP6, TP7, TP8: TestPoint; TestPoint_Loop_D2.60mm_Drill1.4mm_Beaded
U3: 4050; DIP-16_W7.62mm_Socket_LongPads
U4: KS0835F
U5: LM358; DIP-8_W7.62mm_Socket
Z1, Z2: BZX55B2V4-TAP; DO-35

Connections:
+3V3: C8.1, C9.1, R20.1, R26.1, U4.10 (+VDC); also elsewhere on the board
/A_Mute: Q1.2 (G), R26.2; also elsewhere on the board
/Audio_In: C16.1, Q1.3 (D), R20.2, R23.2, R25.1, TP7.1; also elsewhere on the board
/F_R: R12.1, TP3.1, U4.3 (F/R); also elsewhere on the board
/KS0835F SLIC/Audio_In: C11.1; also elsewhere on the board
/KS0835F SLIC/Ring: D2.1 (K), D3.2 (A), R11.2, TP1.1, U4.1 (RING); also elsewhere on the board
/KS0835F SLIC/SHK_Out: R14.1, U4.5 (SHK)
/KS0835F SLIC/SLIC_Ain: C5.1, C12.1, R17.1
/KS0835F SLIC/SLIC_Aout: C6.1, R21.1
/KS0835F SLIC/Tip: D5.1 (K), D6.2 (A), R11.1, TP2.1, U4.2 (TIP); also elsewhere on the board
/KS0835F SLIC/~PD: D7.1 (K), TP8.1
/RM: R13.1, TP4.1, U4.4 (RM); also elsewhere on the board
/SHK: U3.2; also elsewhere on the board
GNDREF: C4.2, C8.2, C9.2, C12.2, C16.2, D2.2 (A), D4.2 (A), D5.2 (A), Q1.1 (S), R12.2, R13.2, R18.2, R24.2, R25.2, U4.9 (GND), U5.3 (+), U5.5 (+), Z2.K; also elsewhere on the board
unnamed: C4.1, R14.2, U3.3
unnamed: C5.2, TP6.1, U4.6 (Audio_In)
unnamed: C6.2, U4.7 (Audio_Out)
unnamed: C7.1, R15.1, R17.2, U5.7
unnamed: C10.1, R15.2, U5.6 (-)
unnamed: C7.2, C10.2, R16.2, R18.1
unnamed: C11.2, R16.1
unnamed: C13.1, C15.2, R19.1, U5.1
unnamed: C13.2, C14.2, R22.2, R24.1
unnamed: C14.1, R19.2, U5.2 (-)
unnamed: C15.1, R23.1
unnamed: D3.1 (K), D4.1 (K), D6.1 (K)
unnamed: D7.2 (A), U4.11 (~PD)
unnamed: R21.2, R22.1, Z1.K
unnamed: Z1.A, Z2.A

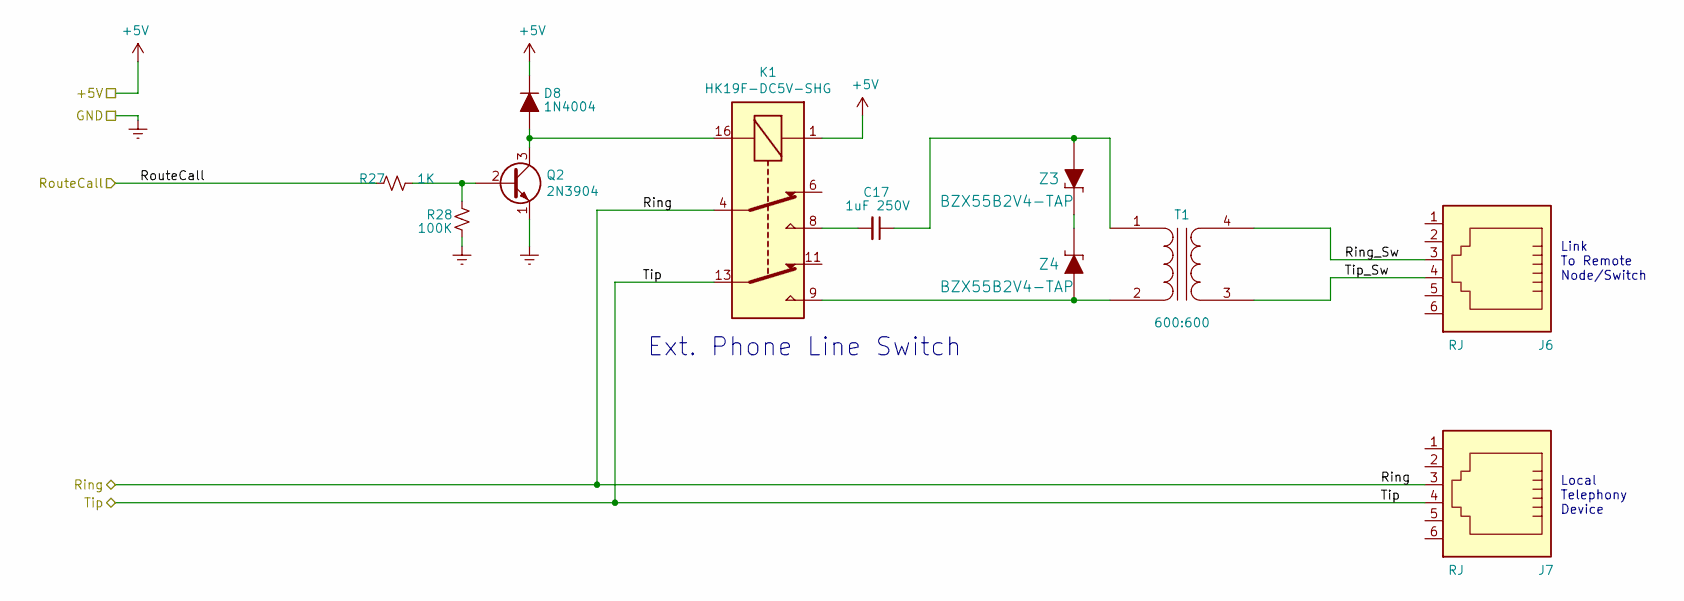
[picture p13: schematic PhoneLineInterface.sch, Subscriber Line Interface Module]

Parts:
C17: 1uF 250V; C_Rect_L16.5mm_W5.0mm_P15.00mm_MKT
D8: 1N4004; D_DO-41_SOD81_P10.16mm_Horizontal
J6, J7: RJ; RJ_6p6c; MFR P/N R-RJ11R06P-A800
K1: HK19F-DC5V-SHG; Relay_DPDT_Omron_G5V-2; MFR P/N HK19F-DC5V-SHG
Q2: 2N3904; TO-92_Inline_Wide
R27: 1K; R_Axial_DIN0207_L6.3mm_D2.5mm_P10.16mm_Horizontal
R28: 100K; R_Axial_DIN0207_L6.3mm_D2.5mm_P10.16mm_Horizontal
T1: 600:600; Transformer_600_600; MFR P/N EL14
Z3, Z4: BZX55B2V4-TAP; DO-35

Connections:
+5V: D8.1 (K), K1.1; also elsewhere on the board
/KS0835F SLIC/Ring: J7.3, K1.4; also elsewhere on the board
/KS0835F SLIC/Tip: J7.4, K1.13; also elsewhere on the board
/Phone Line Interface/Ring_Sw: J6.3, T1.4 (SB)
/Phone Line Interface/Tip_Sw: J6.4, T1.3 (SA)
/RouteCall: R27.1; also elsewhere on the board
GNDREF: Q2.1 (E), R28.1; also elsewhere on the board
unnamed: C17.1, T1.1 (AA), Z3.A
unnamed: C17.2, K1.8
unnamed: D8.2 (A), K1.16, Q2.3 (C)
unnamed: K1.9, T1.2 (AB), Z4.A
unnamed: Q2.2 (B), R27.2, R28.2
unnamed: Z3.K, Z4.K

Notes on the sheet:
Link To Remote Node/Switch
Ext. Phone Line Switch
Local Telephony Device

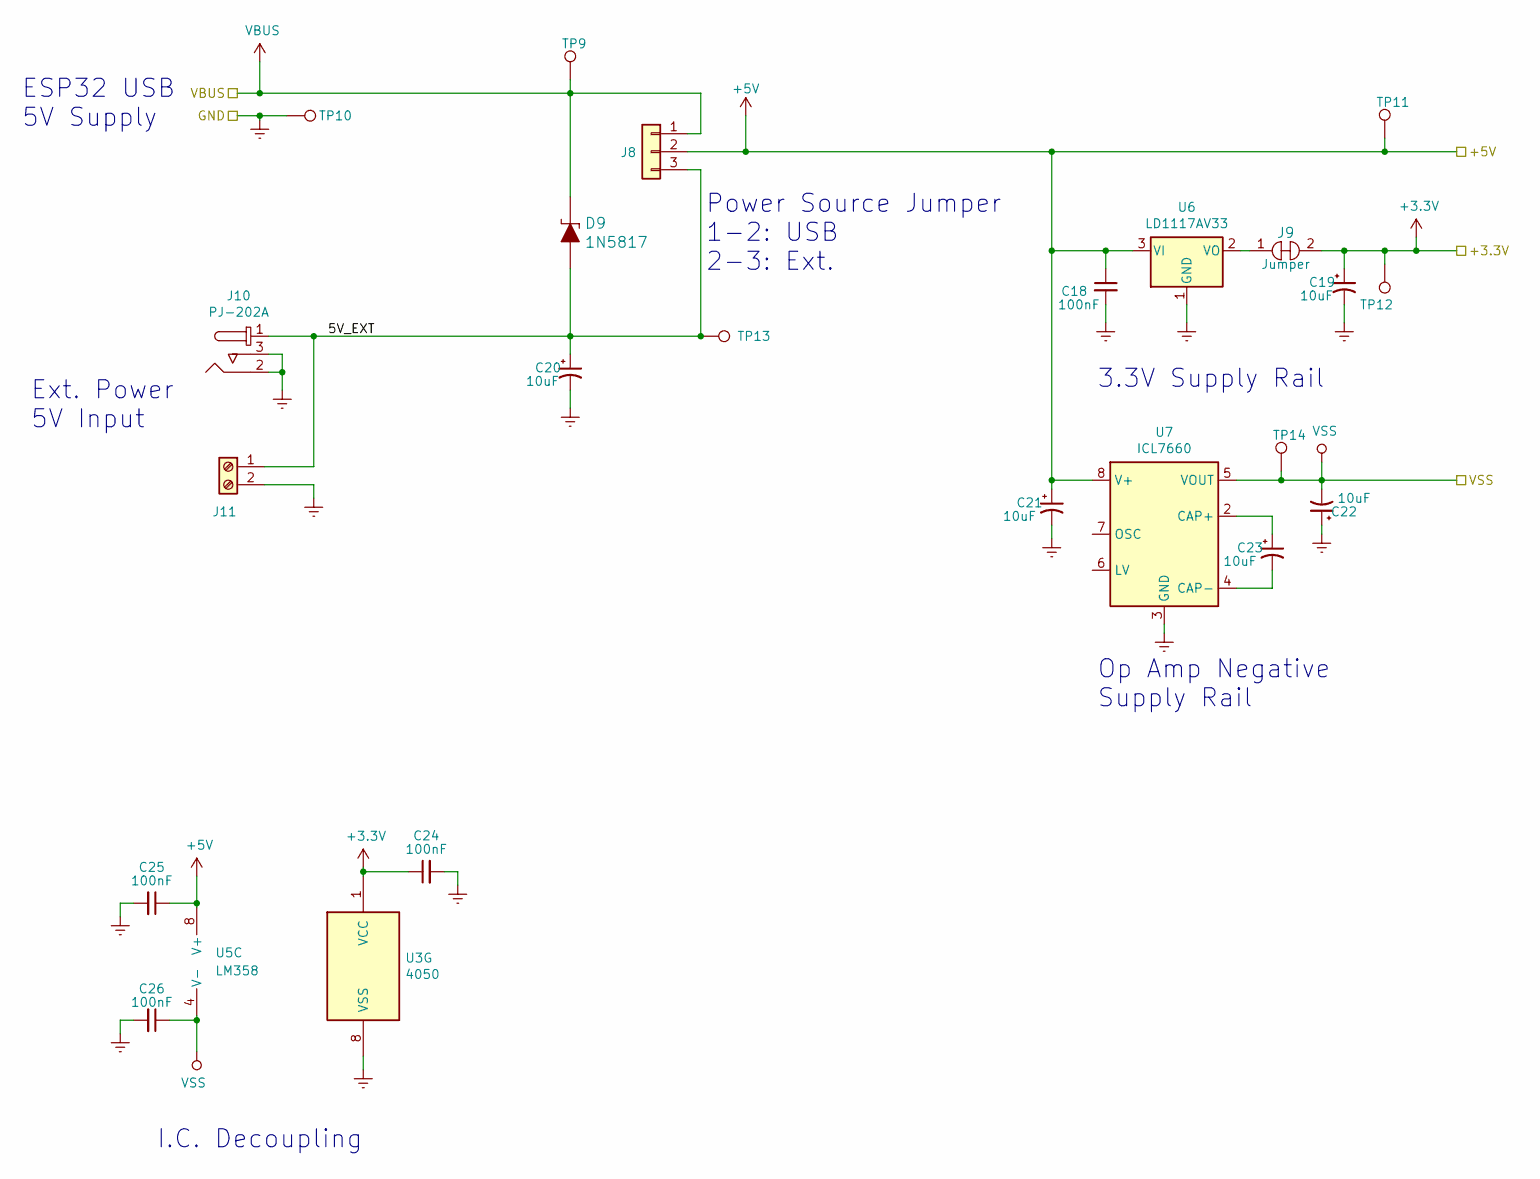
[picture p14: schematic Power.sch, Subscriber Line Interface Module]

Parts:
C18, C24, C25, C26: 100nF; C_Disc_D4.3mm_W1.9mm_P5.00mm
C19, C20, C21, C22, C23: 10uF; CP_Radial_D5.0mm_P2.50mm
D9: 1N5817; DO-41; MPN 1N5817; Digi-Key_PN 1N5817FSCT-ND
J8: Conn_01x03; PinHeader_1x03_P2.54mm_Vertical
J9: Jumper; SolderJumper-2_P1.3mm_Bridged_Pad1.0x1.5mm
J10: PJ-202A; Barrel_Jack_5.5mmODx2.1mmID_PJ-202A; MPN PJ-202A; Digi-Key_PN CP-202A-ND
J11: Screw_Terminal_01x02; TerminalBlock_bornier-2_P5.08mm
TP9, TP10, TP11, TP12, TP13, TP14: TestPoint; TestPoint_Loop_D2.60mm_Drill1.4mm_Beaded
U3: 4050; DIP-16_W7.62mm_Socket_LongPads
U5: LM358; DIP-8_W7.62mm_Socket
U6: LD1117AV33; TO-220-3_Vertical
U7: ICL7660; DIP-8_W7.62mm_Socket

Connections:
+3V3: C19.1, C24.1, J9.2, TP12.1, U3.1 (VCC); also elsewhere on the board
+5V: C18.1, C21.1, C25.1, J8.2, TP11.1, U5.8 (V+), U6.3 (VI), U7.8 (V+); also elsewhere on the board
/Power Rails/5V_EXT: C20.1, D9.A, J8.3, J10.1, J11.1, TP13.1
GNDREF: C18.2, C19.2, C20.2, C21.2, C22.1, C24.2, C25.2, C26.2, J10.2, J10.3, J11.2, TP10.1, U3.8 (VSS), U6.1 (GND), U7.3 (GND); also elsewhere on the board
unnamed: C23.1, U7.2 (CAP+)
unnamed: C23.2, U7.4 (CAP-)
unnamed: J9.1, U6.2 (VO)
VBUS: D9.K, J8.1, TP9.1; also elsewhere on the board
VSS: C22.2, C26.1, TP14.1, U5.4 (V-), U7.5 (VOUT)

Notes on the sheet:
Power Source Jumper 1-2: USB 2-3: Ext.
Op Amp Negative Supply Rail
Ext. Power 5V Input
3.3V Supply Rail
I.C. Decoupling
ESP32 USB 5V Supply

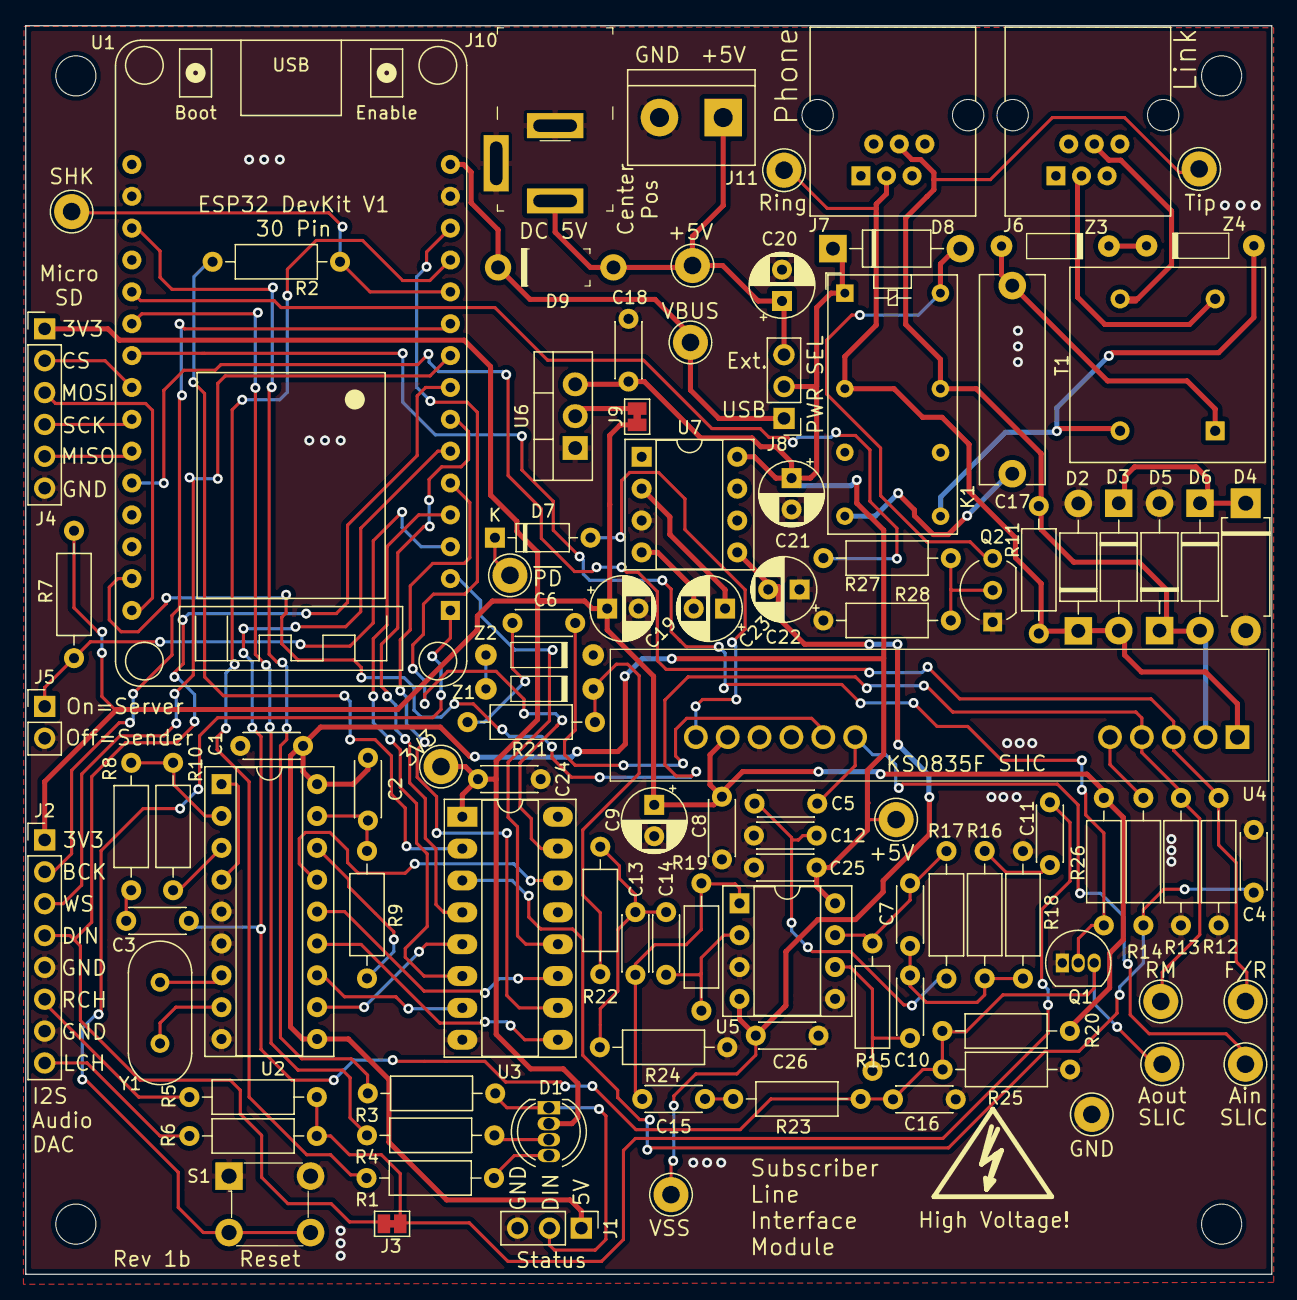
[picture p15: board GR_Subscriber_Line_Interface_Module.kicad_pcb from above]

Board: 2 copper layers, 99.3 x 99.5 mm, 109 parts (0 on the bottom side), 81 nets.

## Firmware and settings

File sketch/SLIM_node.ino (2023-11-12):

/*
    Plain Old Telephone Service (POTS) simulator
    Uses 30 pin ESP32 DOIT Devkit V1 module
    Choose Arduino IDE board "DOIT ESP32 DEVKIT V1"

    Uses a subscriber line interface circuit (SLIC) module KS0835F
    Can generate DTMF call progress tones (selectable regions) using mozzi audio library
    Can play back "This is a recording" audio sample stored in program memory using mozzi

    Coordinates with another node wirelessly using ESP-NOW to place or receive calls
    The node configured as a "Server" via a jumper will create a web page interface

    Some classes and function concepts were borrowed from a similar project:
    https://github.com/ktownsend-personal/RetroPhone


   Libraries:   ArduinoJSON by Benoit Blanchon
                https://github.com/me-no-dev/ESPAsyncWebServer
                https://github.com/me-no-dev/AsyncTCP
                RGBLED https://github.com/wilmouths/RGBLed    (install library by adding zip file downloaded from github
                                                                click "code" button and download zip)
                Mozzi sound library https://github.com/sensorium/Mozzi

                Mozzi documentation/API https://sensorium.github.io/Mozzi/doc/html/index.html

   Tested with Arduino IDE 1.8.13
               ESP32 board file 1.0.6
               ArduinoJSON 6.19.4

   Gadget Reboot
   https://www.youtube.com/@gadgetreboot
*/

#define DEBUG                     // uncomment to allow debug serial messages
#include "DebugUtils.h"
#include "project_globals.h"      // global variables that get referenced in multiple files
#include "miscFunctions.h"        // some things kept here to de-clutter main file
#include "wifiFunctions.h"        // wireless functionality
#include "pulseHandler.h"         // pulse dialing handler
#include "mozzi_call_progress.h"  // class to generate region specific call progress tones
#include <RGBLed.h>               // RGB LED library for 4 pin LED

// pulse dial started callback
void dialingStartedCallback(bool isTone) {
  //
}

auto pulser  = pulseHandler(slic_SHK, dialingStartedCallback);  // pulse dial handler

// create call progress tone generator based on specified geographical region
mozzi_call_progress callProgressGen(myRegion);

// SHK interrupt routine (phone hook switch detection)
void IRAM_ATTR isrSHK() {
  SHK_irqFlag = true;             // set irq flag so it can be handled in main loop
}

// DTMF interrupt routine
void IRAM_ATTR isrDTMF() {
  DTMF_irqFlag = true;            // set irq flag so it can be handled in main loop
}

void setup() {
  Serial.begin(115200);
  Serial.println("\r\nSubscriber Line Interface Module");

  digitalWrite(relayPin, LOW);              // make sure tip/ring trunk line is disengaged
  pinMode(relayPin, OUTPUT);

  // configure gpio
  pinMode(LED_BUILTIN, OUTPUT);             // show wifi connection status on ESP LED when module is a server
  pinMode(senderServerPin, INPUT);          // jumper decides if this node acts as a server or sender node.  pin has an external pull up resistor

  wifiMode = digitalRead(senderServerPin);  // set this node as a wifi sender or server based on jumper setting
  if (wifiMode == wifiServer) initServer();
  else initSender();

  pulser.setMaybeCallback(maybeDialingStartedCallback);
  pulser.setDigitCallback(digitReceivedCallback);
  pulser.start();                                          // prepare pulse dial handler

  initSlic();                       // configure SLIC control pins and phone ring cadence based on set region
  initSystem();                     // init the system and set status flags
  initMT8870();                     // configure hardware dtmf decoder pins

  attachInterrupt(digitalPinToInterrupt(slic_SHK), isrSHK, CHANGE);  // SLIC hook switch triggers an interrupt for off hook and rotary dial signaling
  attachInterrupt(digitalPinToInterrupt(StD), isrDTMF, RISING);      // DTMF data valid interrupt
}

void loop() {

  static unsigned long nodePingTimer = millis();                // timer for pinging msgs between nodes to test connection, send status etc
  const unsigned long nodePingInterval_mS = 60000;

  // periodic wireless activity ping
  if ((millis() - nodePingTimer) > nodePingInterval_mS) {
    nodePingTimer = millis();
    sendTrunkMsg(localPhoneNumber, "", NONE, NIL);              // send a message to other node just to see there is communication
  }

  runStateMachine();          // handle state machine operations
  checkIRQ();                 // process any pending interrupts for SHK or dialing events
  callProgressGen.update();   // handle audio generation operations if in progress
  pulser.run();               // handle pulse dial operations if in progress

  // debounce SHK if it has changed state
  // this could be implemented better but software isn't my first language
  unsigned long lapsedTime = millis() - shkDebounceTimer;
  if (shkTimerRunning && (lapsedTime >= shkDebounceInterval)) {  // if hook switch has been debounced, determine its final state
    shkTimerRunning = false;
    stateOffhook = digitalRead(slic_SHK);

    // if going off hook, update hook switch after debounce
    // if going on hook, wait for the longer on-hook delay to confirm it wasn't pulse dialing
    if (stateOffhook)
      bitSet(sysFlags, sysFlag_offHook);
    //  else
    //    bitClear(sysFlags, sysFlag_offHook);
    // Serial.println(stateOffhook ? "Off hook" : "On hook");    // test if SHK is being detected
  }


  // if phone went on-hook, verify if it was a hang up vs pulse dial event
  // this needs to be more robust eg. read SHK every 30 mS or something and be sure it was on hook each time?
  lapsedTime = millis() - shkOnHookTimer;
  if (shkOnHookTimerRunning && (lapsedTime >= shkOnHookInterval)) {
    shkOnHookTimerRunning = false;
    if (!pulseDialingNow) {                         // if a pulse dialed digit has not been detected by now, it was a hang-up event
      if (!digitalRead(slic_SHK))                   // if SHK is still low, register the hang up event
        bitClear(sysFlags, sysFlag_offHook);
    }
  }




  // when in dialing mode, accumulate DTMF digits until there is a phone number to dial
  if (bitRead(sysFlags, sysFlag_dialMode)) {
    if (bitRead(sysFlags, sysFlag_StD_trig)) {
      bitClear(sysFlags, sysFlag_StD_trig);
      char c_read = readDtmf();
      if (c_read != ' ') {                          // if a new DTMF key has been read
        callProgressGen.audioStop();                // stop playing dialtone when phone keys get pressed
        dialedNumber += c_read;       // append dtmf character to dialed number
        DEBUG_PRINT( F("Dialed digits so far: ") );
        DEBUG_PRINTLN(dialedNumber);
      }
    }
  }

}  // end loop

void maybeDialingStartedCallback() {
  // any purpose?
}


// pulse dial digit callback
void digitReceivedCallback(char digit) {
  //timeoutStart();           // reset timeout after user input
  //Serial.print(digit);      // debug output show digits as they are received
  callProgressGen.audioStop();                // stop playing dialtone when phone keys get pressed
  dialedNumber += digit;          // accumulate the digit

  DEBUG_PRINT(F("[pulse digit] "));
  DEBUG_PRINTLN(digit);

  DEBUG_PRINT( F("Dialed digits so far: ") );
  DEBUG_PRINTLN(dialedNumber);

}



void runStateMachine() {
  enum states {
    startup,                   // initial state at system reset
    idle,                      // standby mode waiting for activity to occur
    acceptDialInput,           // phone went off hook, accumulate dialed digits
    attemptPlaceCall,          // try to place a call when a number is dialed
    waitForCallPlaceResponse,  // wait until remote node responds to call request, or a timeout occurs
    remotePhoneRinging,        // destination phone is ringing.  wait for remote phone to go off hook so nodes can be connected
    ringPhone,                 // ring the local phone to indicate there is an incoming call
    connectCall                // proceed to connect tip/ring trunk line between local and remote node
  };

  static enum states currState = startup;                           // initial state is "startup"
  static boolean enteringNewState = true;                           // whether or not the current state is just beginning
  static unsigned long nodeResponseTimer = millis();                // timer for awaiting responses from remote nodes
  static const unsigned long nodeResponseTimerInterval_mS = 10000;
  static unsigned long offhookTimer = millis();                     // timer to track if phone is off hook too long without a call connected
  static const unsigned long offhookTimerInterval_mS = 15000;       // timeout period before playing "this is a recording" message
  static unsigned long howlerTimer = millis();
  static const unsigned long howlerTimerInterval_mS = 20000;        // timeout period before playing howler tone when off hook too long

  // if phone number is taking too long to finish dialing,
  // play "this is a recording" message
  if ((bitRead(sysFlags, sysFlag_enableTimer1)) && !(currState == connectCall)  && (!bitRead(sysFlags, sysFlag_timer1Exp))) {
    if (!(dialedNumber == "")) {                                 // only play recorded message if dialing was in progress and took too long
      if ((millis() - offhookTimer) > offhookTimerInterval_mS) {
        DEBUG_PRINTLN( F("[note] Start playing 'this is a recording' message") );
        howlerTimer = millis();                                  // if recorded message is played, restart howler timer to play after recording
        bitSet(sysFlags, sysFlag_timer1Exp);                     // indicate recording has started playing after timer delay expired
        bitClear(sysFlags, sysFlag_enableTimer1);                // disable recording delay timer once playback has started
        callProgressGen.audioStop();                             // cancel any call progress audio tones that were playing
        callProgressGen.thisIsARecordingStart();                 // begin playing recorded message
      }
    }
  }

  // if phone is off hook for too long without a call being connected, play howler tone
  if ((bitRead(sysFlags, sysFlag_enableTimer2)) && !(currState == connectCall) && (!bitRead(sysFlags, sysFlag_timer2Exp))) {
    if ((millis() - howlerTimer) > howlerTimerInterval_mS) {
      DEBUG_PRINTLN( F("[note] Howler tone playing") );
      bitSet(sysFlags, sysFlag_timer2Exp);                       // indicate howler has started after timer delay expires
      bitClear(sysFlags, sysFlag_enableTimer2);                  // disable howler delay timer once playback has started
      callProgressGen.audioStop();                               // cancel any call progress audio tones that were playing
      callProgressGen.howlerToneStart();                         // begin playing howler
    }
  }

  switch (currState) {
    case startup:                                                // initial state, perform any first-run operations and go to idle state
      callProgressGen.startup();                                 // initialize mozzi call progress tone generator
      remoteNodeStatus = NIL;                                    // msg originator node's status (available, busy etc)
      remoteRequestType = NONE;                                  // what does originator node want from the destination node
      remotePhoneNum = "";                                       // phone number of remote node contacting local node
      dialedNumber = "";                                         // no local dialing has started yet
      currState = idle;
      enteringNewState = true;
      break;

    case idle:
      if (enteringNewState == true) {                            // run once when transitioning into state
        DEBUG_PRINTLN( F("\r\n[enter state] idle") );
        digitalWrite (relayPin, LOW);                            // ensure tip/ring trunk line is disconnected
        digitalWrite(slic_audioMute, HIGH);                      // disable audio path out of SLIC
        led.setColor(RGBLed::BLUE);                              // set LED to indicate idle
        dialedNumber = "";                                       // prepare to accept a new sequence of digits to dial
        pulseDialingNow = false;                                 // prepare to look for new pulse dial events
        pulser.start();                                          // prepare pulse dial handler
        bitClear(sysFlags, sysFlag_dialMode);                    // don't process dialed digits unless placing a call
        bitClear(sysFlags, sysFlag_timer1Exp);                   // reset offhook timeout indicators
        bitClear(sysFlags, sysFlag_timer2Exp);
        bitClear(sysFlags, sysFlag_enableTimer1);
        bitClear(sysFlags, sysFlag_enableTimer2);
        callProgressGen.audioStop();                             // cancel any audio that may be playing
        setNodeAvailable(true);                                  // this node is available for calls
        enteringNewState = false;
      }
      if (offHook()) {                                           // if phone goes off hook, prepare for dialing
        setNodeAvailable(false);                                 // this node is not available for calls
        offhookTimer = millis();                                 // enable offhook timers for recorded message and howler playback if there is a timeout
        howlerTimer = millis();
        bitSet(sysFlags, sysFlag_enableTimer1);
        bitSet(sysFlags, sysFlag_enableTimer2);
        digitalWrite(slic_audioMute, LOW);                       // enable audio path out of SLIC
        led.setColor(RGBLed::MAGENTA);                              // set LED to indicate off hook
        enteringNewState = true;
        currState = acceptDialInput;
      }
      if (remoteRequestType == INCOMING_CALL) {                  // if wireless msg is received and remote node is attempting to call this node
        clearRemoteNodeData();                                   // msg has been received and processed so clear msg data
        enteringNewState = true;
        currState = ringPhone;                                   // ring the local phone and wait for a pick up off hook
      }
      break;

    case acceptDialInput:
      if (enteringNewState == true) {                            // run once when transitioning into state
        DEBUG_PRINTLN( F("[enter state] acceptDialInput") );
        bitSet(sysFlags, sysFlag_dialMode);                      // start accumulating dialed digits to dial a number
        callProgressGen.dialToneStart();                         // play call progress dial tone in local phone while waiting for dialed digits
        enteringNewState = false;
      }
      if (!offHook()) {                                          // if phone goes on hook, cancel dialing
        callProgressGen.audioStop();                             // stop playing dialtone
        bitClear(sysFlags, sysFlag_dialMode);                    // don't process dialed digits unless placing a call
        enteringNewState = true;
        currState = idle;
      }

      if (dialedNumber.length() == 7) {
        if (dialedNumber == remotePhoneNumber) {                   // try to place a call if a valid phone number is dialed
          bitClear(sysFlags, sysFlag_dialMode);                    // stop processing dialed digits
          bitClear(sysFlags, sysFlag_enableTimer1);                // don't timeout for incorrect dialed number anymore
          bitClear(sysFlags, sysFlag_enableTimer2);
          enteringNewState = true;
          currState = attemptPlaceCall;
        }
      }
      break;

    case attemptPlaceCall:
      if (enteringNewState == true) {                            // run once when transitioning into state
        enteringNewState = false;
      }
      // send a message containing this node's local number, the number of the target node, requesting to place an
      // incoming call to target node, and this node is currently busy (trying to place this call)
      sendTrunkMsg(localPhoneNumber, dialedNumber, INCOMING_CALL, NODE_BUSY);
      nodeResponseTimer = millis();                              // start a timer while waiting for response from remote node
      enteringNewState = true;
      currState = waitForCallPlaceResponse;
      break;

    case waitForCallPlaceResponse:
      if (enteringNewState == true) {                            // run once when transitioning into state
        DEBUG_PRINTLN( F("[enter state] waitForCallPlaceResponse") );
        enteringNewState = false;
      }

      if ((millis() - nodeResponseTimer) > nodeResponseTimerInterval_mS) {
        enteringNewState = true;
        currState = idle;                                        // remote node didn't respond in time, call failed, go back to idle
      }

      if (remoteNodeStatus == NODE_AVAILABLE) {                  // remote node is available for a call so generate call progress ring tone
        clearRemoteNodeData();                                   // msg has been received and processed so reset data for next msg attempt
        enteringNewState = true;
        currState = remotePhoneRinging;
      }

      if (remoteNodeStatus == NODE_BUSY) {                       // remote node is busy, can't complete the call
        clearRemoteNodeData();                                   // msg has been received and processed so reset data for next msg attempt
        callProgressGen.busyToneStart();                         // play call progress busy signal to alert caller of status
      }

      if (!offHook()) {                                               // if phone goes on hook before call is connected, end call attempt
        sendTrunkMsg(localPhoneNumber, dialedNumber, NONE, ON_HOOK);  // notify other node the call is aborted
        enteringNewState = true;
        currState = idle;
      }
      break;

    case remotePhoneRinging:
      if (enteringNewState == true) {                            // run once when transitioning into state
        DEBUG_PRINTLN( F("[enter state] remotePhoneRinging") );
        callProgressGen.ringToneStart();                         // start playing call progress ring tone to alert caller of status
        enteringNewState = false;
      }
      if (remoteNodeStatus == OFF_HOOK) {                        // remote phone has been answered, call can be connected
        clearRemoteNodeData();                                   // msg has been received and processed so reset data for next msg attempt
        enteringNewState = true;
        currState = connectCall;
      }

      if (!offHook()) {                                               // if phone goes on hook before remote node answers, end the call
        sendTrunkMsg(localPhoneNumber, dialedNumber, NONE, ON_HOOK);  // notify other node the call is aborted
        enteringNewState = true;
        currState = idle;
      }
      break;

    case ringPhone:
      if (enteringNewState == true) {                             // run once when transitioning into state
        DEBUG_PRINTLN( F("[enter state] ringPhone") );
        setNodeAvailable(false);                                  // this node is not available for new calls
        ringGenStart();                                           // ring the local phone
        // remote node has sent a msg that they would like to place a call to this node, which is available, so
        // send a message containing this node's local number, the number of the target node, requesting nothing,
        // and replying that this node is available to receive a call
        sendTrunkMsg(localPhoneNumber, dialedNumber, NONE, NODE_AVAILABLE);
        enteringNewState = false;
      }

      if (bitRead(sysFlags, sysFlag_ringing)) {                   // if SLIC is ringing the phone, handle the control signals
        slicRingGenerate();
      }

      // *** note to future self ***
      // need to add a check to see if there was a message from remote side that the call is cancelled, then go back to idle?

      if (offHook()) {                                                 // if phone is answered, connect the call
        slicRingStop();                                                // stop ringing local phone
        sendTrunkMsg(localPhoneNumber, dialedNumber, NONE, OFF_HOOK);  // send message to confirm call has been answered
        enteringNewState = true;
        currState = connectCall;
      }

      if (remoteNodeStatus == ON_HOOK) {                          // remote phone has been hung up, abort call
        clearRemoteNodeData();                                    // msg has been received and processed so reset data for next msg attempt
        enteringNewState = true;
        currState = idle;
      }
      break;

    case connectCall:
      if (enteringNewState == true) {                             // run once when transitioning into state
        digitalWrite (relayPin, HIGH);                            // turn on tip/ring trunk line relay when a call is established
        callProgressGen.audioStop();                              // cancel any call progress audio tones that were playing
        led.setColor(RGBLed::GREEN);                              // set LED to indicate call connected
        DEBUG_PRINTLN( F("[enter state] connectCall") );
        enteringNewState = false;
      }

      if (!offHook()) {                                               // if phone goes on hook, end call
        sendTrunkMsg(localPhoneNumber, dialedNumber, NONE, ON_HOOK);  // notify other node the call is aborted
        enteringNewState = true;
        currState = idle;
      }
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

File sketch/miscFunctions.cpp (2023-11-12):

/*
    functions offloaded here to keep things uncluttered
*/

#include "miscFunctions.h"

// initialize the system and set status flags to default states
void initSystem() {
  led.setColor(RGBLed::YELLOW);
  
  if (digitalRead(slic_SHK))                  // check if phone is on or off hook
    bitSet(sysFlags, sysFlag_offHook);
  else
    bitClear(sysFlags, sysFlag_offHook);
  bitClear(sysFlags, sysFlag_ringing);        // ensure phone is not ringing when initializing the system
  bitClear(sysFlags, sysFlag_dialMode);       // not accepting dialed digits unless in dial mode
  bitClear(sysFlags, sysFlag_dtmfData);       // assume no dtmf data needs to be decoded
  bitClear(sysFlags, sysFlag_StD_trig);       // assume no dtmf tones are detected on phone line
  bitSet(sysFlags, sysFlag_nodeBusy);         // node is busy until system is idle
  bitClear(sysFlags, sysFlag_timer1Exp);      // timer not expired
  bitClear(sysFlags, sysFlag_timer2Exp);      // timer not expired
  bitClear(sysFlags, sysFlag_enableTimer1);   // timer disabled
  bitClear(sysFlags, sysFlag_enableTimer2);   // timer disabled
}

// North America ring cadence  2s on/4s off
void ringNorthAmericaInit() {
  ringCadence[0] = 2000;
  ringCadence[1] = 4000;
  ringCadence[2] = 0;
  ringCadence[3] = 0;
}

// UK ring cadence  0.4s on/0.2s off/0.4s on/2s off
void ringUkInit() {
  ringCadence[0] = 400;
  ringCadence[1] = 200;
  ringCadence[2] = 400;
  ringCadence[3] = 2000;
}

// configure SLIC pins and ring patterns based on region
void initSlic() {
  // configure SLIC module pins
  digitalWrite(slic_fwdRev, LOW);
  digitalWrite(slic_ringMode, LOW);
  digitalWrite(slic_audioMute, HIGH);   // disable audio path out of SLIC

  pinMode(slic_fwdRev, OUTPUT);
  pinMode(slic_ringMode, OUTPUT);
  pinMode(slic_audioMute, OUTPUT);
  pinMode(slic_SHK, INPUT);

  switch (myRegion) {
    case northAmerica:
      ringNorthAmericaInit();
      break;

    case uk:
      ringUkInit();
      break;

    default:
      ringNorthAmericaInit();
      break;
  }
}

// configure pins for mt8870 dtmf decoder
void initMT8870() {
  pinMode(Q1, INPUT);
  pinMode(Q2, INPUT);
  pinMode(Q3, INPUT);
  pinMode(Q4, INPUT);
  pinMode(StD, INPUT);
}

// process IRQ events
void checkIRQ() {
  if (SHK_irqFlag) {
    SHK_irqFlag = false;                                 // clear interrupt flag

    // read the hook switch and if it has transitioned,
    // allow settling for 10 mS and take a final reading to accept as the new hook state
    bool currSHK = digitalRead(slic_SHK);                // check current state of hook switch

    if (stateOffhook && !currSHK && !shkTimerRunning) {  // start a debounce timer when SHK goes low
      shkTimerRunning = true;
      shkOnHookTimerRunning = true;
      shkDebounceTimer = millis();                       // overall SHK debounce timer
      shkOnHookTimer = millis();                         // SHK going on-hook vs pulse dialing timer
    }

    if (!stateOffhook && currSHK && !shkTimerRunning) {  // start a debounce timer when SHK goes high
      shkTimerRunning = true;
      shkDebounceTimer = millis();
    }
  } // end SHK_irqFlag

  if (DTMF_irqFlag) {
    DTMF_irqFlag = false;                                // clear interrupt flag
    bitSet(sysFlags, sysFlag_StD_trig);                  // set a flag to go read dtmf data for a dialed digit
  } // end DTMF_irqFlag
}

// print out the system flags in serial monitor if requested
void debug_print_sysflags() {
  Serial.print("Debug sysflags: ");
  if  (bitRead(sysFlags, sysFlag_dialMode))
    Serial.print("Accepting Dialed Digits | ");
  else
    Serial.print("Not Accepting Dialed Digits | ");

  if  (bitRead(sysFlags, sysFlag_dtmfData))
    Serial.print("DTMF Tone | ");
  else
    Serial.print("DTMF None | ");

  if  (bitRead(sysFlags, sysFlag_StD_trig))
    Serial.print("DTMF Triggered | ");
  else
    Serial.print("DTMF !Trig | ");

  if  (bitRead(sysFlags, sysFlag_offHook))
    Serial.print("Off Hook | ");
  else
    Serial.print("On Hook | ");

  if  (bitRead(sysFlags, sysFlag_enableTimer1))
    Serial.print("Timer 1 Enabled | ");
  else
    Serial.print("Timer 1 Disabled | ");

  if  (bitRead(sysFlags, sysFlag_enableTimer2))
    Serial.print("Timer 2 Enabled | ");
  else
    Serial.print("Timer 2 Disabled | ");

  if  (bitRead(sysFlags, sysFlag_timer1Exp))
    Serial.print("Timer 1 Expired | ");
  else
    Serial.print("Timer 1 Not Expired | ");

  if  (bitRead(sysFlags, sysFlag_timer2Exp))
    Serial.print("Timer 2 Expired | ");
  else
    Serial.print("Timer 2 Not Expired | ");

  if  (bitRead(sysFlags, sysFlag_ringing))
    Serial.print("Ringing | ");
  else
    Serial.print("Not Ringing | ");

  if  (bitRead(sysFlags, sysFlag_nodeBusy))
    Serial.print("Node Busy");
  else
    Serial.print("Node Available");

  Serial.println("");
}

// check if phone is on or off hook
bool offHook() {
  return (bitRead(sysFlags, sysFlag_offHook));
}

// check if this node is available for a call or busy
bool nodeBusy() {
  return (bitRead(sysFlags, sysFlag_nodeBusy));
}

// set availability status of this node
void setNodeAvailable(bool available = true) {
  if (available)
    bitClear(sysFlags, sysFlag_nodeBusy);
  else
    bitSet(sysFlags, sysFlag_nodeBusy);
}

// clear received msg data once processed so it is not confused for new data later
void clearRemoteNodeData() {
  remotePhoneNum = "";                        // msg originator node's phone number
  remoteNodeStatus = NIL;                     // msg originator node's status (available, busy etc)
  remoteRequestType = NONE;                   // what does originator node want from the destination node
}

void slicRingStop() {
  digitalWrite(slic_fwdRev, LOW);             // stop generating ring signal on SLIC
  digitalWrite(slic_ringMode, LOW);
  bitClear(sysFlags, sysFlag_ringing);        // phone is not ringing, clear system status flag
  led.off();                                  // turn off ring indicator LED

  // *** Double check slic documentation regarding the need for a delay for voltages to settle***
}

// start ringing the phone connected to the SLIC
void ringGenStart() {
  if (offHook()) return;                      // don't try to ring a phone unless it is on hook
  slic_ring_cadence_step = 0;                 // start from the beginning of the ring cadence pattern
  slic_timer = millis();                      // start a timer for phone ringing cadence
  slic_ring_freq_timer = millis();            // start a timer for phone ringing freq
  bitSet(sysFlags, sysFlag_ringing);          // phone is ringing, set system status flag
  digitalWrite(slic_ringMode, HIGH);          // set SLIC in ring generation mode
}
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

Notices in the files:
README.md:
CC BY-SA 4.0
